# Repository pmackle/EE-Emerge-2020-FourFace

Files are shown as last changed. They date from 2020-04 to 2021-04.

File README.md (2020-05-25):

---
title: Readme
layout: template
filename: README
--- 

# EE-Emerge 2020: Four Face

FourFace is a capacitive touch, four player interactive game in the vein of the 80's electronic game, "Simon".  The basic premise of the game is a pattern of lights will emit for each player that they will then have to replicate. If they guess incorrectly, they are eliminated. With each round the patterns become more complex

## Table of Contents

1. [About the Project](#about-the-project)
1. [Getting Started](#getting-started)
    1. [Dependencies](#dependencies)
    1. [Installation](#installation)
1. [How to Get Help](#how-to-get-help)
1. [Authors](#authors)
1. [Acknowledgements](#acknowledgements)

# About the Project
FourFace is a project developed during the 2019/2020 academic year by undergraduates from EE-Emerge a group within the Department of Electrical and Computer Engineering at the University of California, Davis. FourFace is interactive memory game where four players compete against one another by replicating randomly generated patterns. As the rounds increase, the patterns become more difficult. Once a person fails to imitate the given pattern, they are eliminated. Last person to survive the remaining rounds is crowned the winner. At the core of FourFace's technology is CapSense technology and custom PCBs.

Features:
- CapSense Technology
- Custom PCB's
- 1-4 player game
- Adjustable Difficulty
- Portable
The mechanical design for the project is composed of a 15x15in cube with 9 acrylic tiles that face each player.

Our motivation for the project was to put a creative, more modern spin on a similar, but older game. We wanted to use our engineering skills to bring a faint idea into a reality by overseeing it through the whole product lifecycle. 

[Our Hackster.io website](https://www.hackster.io/fourface/fourface-1bf273)

**[Back to top](#table-of-contents)**

# Getting Started
These instructions will get you a copy of the project up and running on your local machine for development and testing purposes. See deployment for notes on how to deploy the project on a live system.

## Dependencies

### Required 
In order to build the firmware, [TI Code Composer](https://software-dl.ti.com/ccs/esd/documents/ccs_downloads.html) should be installed. When prompted select to add support for MSP430 and MSP432 microcontrollers. 

### Optional
Segger J-Link support can be added for MSP432, but is not required.

## Getting the Source

This project is [hosted on GitHub](hhttps://github.com/pmackle/EE-Emerge2020-FourFace). You can clone this project directly using this command:

```
git clone https://github.com/pmackle/EE-Emerge2020-FourFace
```

This will create a new root folder "EE-Emerge2020-FourFace" that will contain all projects for Four Face.

## Installation

1. Open Code Composer Studio
1. Create a new workspace 
    * File -> Switch Workspace -> Other
1. Browse to where the project repository was closed. 
1. Press launch
1. Import projects
    1. Project -> Import CCS Projects
    1. Press Browse
    1. Select root folder that was cloned.
    1. Press OK 
    1. Checkmark all projects
    1. Press Finish
1. Build each project one by one

**[Back to top](#table-of-contents)**

# How to Get Help

For help please contact one of the project [authors](#release-process).

**[Back to top](#table-of-contents)**

# Authors

* [Patrick Mackle](https://github.com/pmackle) - *Team Leader, Mechanical Design, Fabrication*
* [Anthony Pham](https://github.com/AnthonysPham) - *Mechanical Design, Fabrication*
* [Sophie Bolotin](https://github.com/sbolotin20) - *Website Design*
* [Noah Tarr](https://github.com/NoahTarr) - *Software Design*
* [Vanessa Liera](https://github.com/vpliera) - *Fabrication*
* [Victoria Liera](https://github.com/victorialiera) - *Fabrication*
* [Michelle Acoba](https://github.com/maacoba) - *Fabrication, Website Design*
* [Christian Gonzalez](https://github.com/christian-ee-emerge) - *Hardware & Mechanical Design, Fabrication*
* [Sean Alling](https://github.com/SeanAlling) - *Class TA*
* Andre Knoesen- *Professor*

**[Back to top](#table-of-contents)**

# Acknowledgments

UC Davis for giving us the opportunity to work together & Texas Instruments for sponsoring and allowing for FourFace to even become a reality.
A huge thank you to our professor Andre Knoessen and TA Sean Alling for their guidance in helping us stay on track with our goals and keep our sight on the big picture. 

**[Back to top](#table-of-contents)**

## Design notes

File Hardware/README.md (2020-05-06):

During the prototype phase, we used Texas Instruments MSP430 and MSP432 launchpads to test the capsense technology, the software of the
game, and any wirings we have in mind. Once we figured out what we wanted out of this project, we became designing our PCBs. We will 
continue to use the MSP432 launchpad as our master. The software we will be using to create our PCBs is CircuitMaker by Altium Circuit 
Maker.

Here is a little background information on why we decided to make custom PCBs. At first, we thought of having the nine LED strips 
connected to the face launchpad. Along with the nine capsense acylic panels, the numbers of connections needed became 18 wires plus a 
communication wire, bring the total to 19 wires. However, The MSP430 do not support this many connections. With this in mind, we created 
our PCBs. 

The main job of the face PCBs is to read whether the capsense is activated. If the PCB detects a change in capacitance, then the 
PCB will be able to communicate with the Master PCB through UART. 

START CHANGES
Add some images here of the hardware
END CHANGES

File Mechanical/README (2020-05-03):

  The software app we will be using to cad the design is AutoDesk Fusion 360. A laser cutter is needed to cut the wood sheets for the 
mechanical design. If you do no have a laser cutter, a box cutter will do. You will also need a 3D printer to print any needed parts.
  The overall design of the of the project is a cube, where each of the four adjacent sides make up the frames. Each frame will have a 
dimension of 15x15 inch. Within each frame, there are nine 4x4 inch acrylic panels with capacitive sensing technology, ultimately acting
as a "touch screen." Each frame has four layers, each having a specific mechanical function. The acrylic panel sits on top of the first
layer and the first layer is directly above thesecond layer. The first and second layer act in conjunction with each other by creating 
a stable configuration for the panel, which is the layer above, to sit evenly on the first layer. Because the acrylic panel has the same 
dimensions as the first layer, without the second layer being slightly larger, the panels would be unable to be securely stacked. The next
layer has a specific thickness of half an inch, which is the width the the LED strip we will be using. The LED strip will run along the 
square cutouts. The final layer allows wiring management. Once one frame is done, you have to do the same procedure three more times. To 
attach the layers of the frames, we recommend using wood glue. Now once all four frames are done, you can start assemblng the four 
faces together. In AutoDesk Fusion 360, we cadded a model called corner connector. This is a simple design to assemble the four frames
together. They will lay inside of the cube, in the corner. We can make holes to screw the corner connector and the frame together.
  Lets talk a little more about the acrylic panels with capsense technology. If you look at one acrylic square, you will see copper tape 
surrounding the perimeter. A wire is then soldered onto the copper tape so that we can connect the acrylic squares to the face 
PCB. This will act as a parallel plate while the person's hand will act as the other parallel plate. When the person makes contact with
the acrylic plate, the capacitance will change. If this change passes a certain threshold, the PCB will activate the LED strips.
  There are additional designs that makes the project look cleaner. One of the aesthetic choices is four wooden rectangular dowels. When
the four faces are assembled, the outside corners do not align with each other. By using the dowels, we cna make each face flush with 
each other. Another design choice is having a base and tower underneath the four faces. The tower will be a rectangular box that connects 
the four faces and the base. This will also give the game some height, allowing the players to stand when imitating the pattern. The base 
will be a simple box that houses the power supply.

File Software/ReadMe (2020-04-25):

This project will need four Texas Instruments' MSP430 and one MSP432 launchpad. To program these microcontrollers, we will 
be using Texas Instrument Code Composer Studio. In order to communicate between the master launchpad to the four face microcontroller,
we will be using Universal Asynchronous Receiver/Transmitter (UART) Communication. 
Overview of the Code:
The Master and faces will start up and initilize the game and players. The players will then have to ready up by touching the 
middle panel of the frame. Once readied up, the master will send a random pattern to each frame. The player will memorise the pattern
and imitate the pattern. If the pattern is incorrect, then the player will get eliminated. However, if the player manage to replicate it,
then the player goes onto the next round. There is two ways the game will end: three out of the four players gets eliminated or the 
predetermined set of rounds get completed before elimination occurs.

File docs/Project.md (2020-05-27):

---
title: Project
layout: template
filename: Project
--- 

# FourFace 
FourFace integrates capacitive touch sensing into a four-player interactive game in the vein of the 80's electronic game, "Simon". In the game, a pattern of lights emits and each player tries to replicate. If they guess incorrectly, the player is eliminated. The patterns become increasingly complex with new each round.   

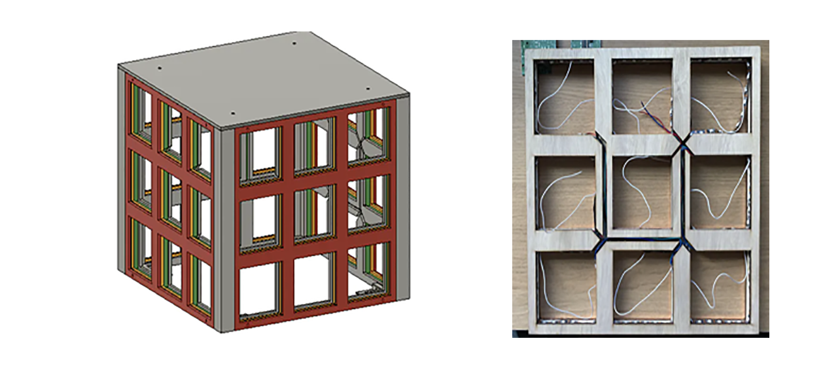
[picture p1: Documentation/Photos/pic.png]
test!


## Mechanical Design

All of the mechanical design was done through Autodesk Fusion 360. Fourface is a cube that consists of 4 sides called "Faces", with 9, 4x4in acrylic tiles. The laser cut sides are held together by 3D printed corner pieces. One whole face is 15x15in.

Each frame has four layers, each with their own specific mechanical function. The first layer and second layer stack such that acrylic tiles can be placed securely on each face. The next layer has bigger holes so as allow for the LED strip to sit flush with the top layers. The final layer allows for cleaner wiring in a specific order.

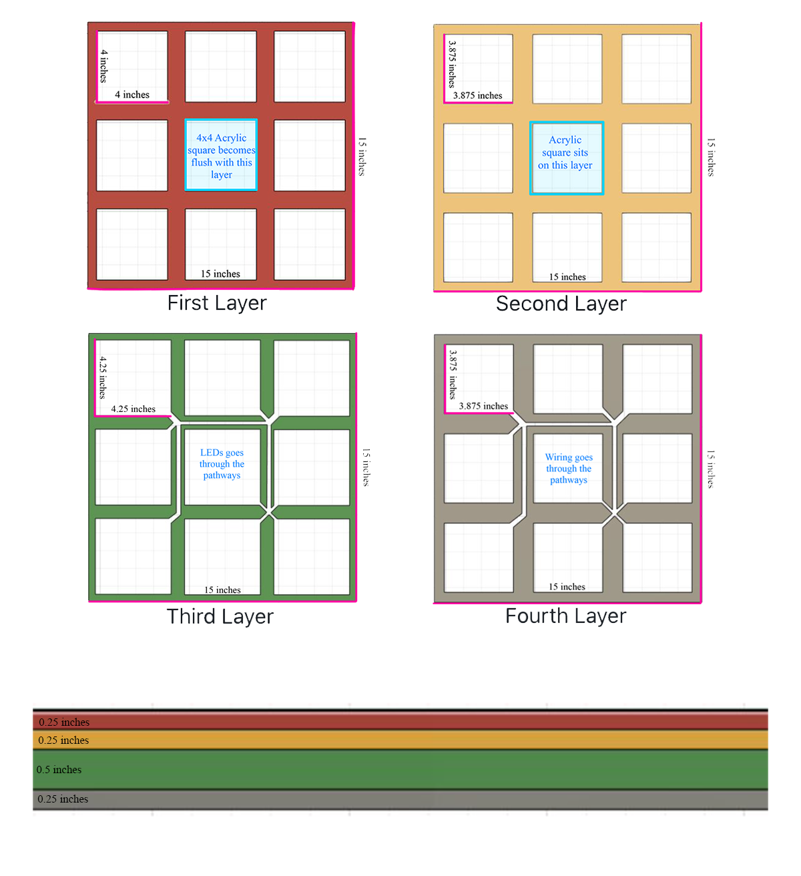
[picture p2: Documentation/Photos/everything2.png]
firstsecond!


## Software Design 

The project consists of four Texas Instruments' MSP430 and one MSP432 Launchpad. We use Universal Asynchronous Receiver/Transmitter (UART) Communication, allowing the communication between the master (MSP432) and slaves (MSP430). The master launchpad creates a random pattern and sends the pattern to the slaves. Once the pattern is received, the slaves display the pattern for the player to irepeat.

## Capacitive Touch

Texas Instruments' MSP430 has up to 16 capacitive touch pins embedded into its system. To build the capacitive touch system, we laser cut acrylic squares that acted as "touch screen buttons" for the users to press. Copper tape surrounds the tiles to allow for the system to recognize a change in capacitance. Wires are soldered onto the copper tape and connect to the PCB.

When a person makes contact (or comes near) the acrylic or copper tape, the capacitance changes. In summary, the finger and the system act as parallel plate capacitors. Our code counts the number of charges and discharges to 5 volts. When the capacitive touch system is untouched, there is a certain "untouched" threshold value. Because capacitance is inversely proportional to distance, we are able to use that change and tell the microcontroller that the tile has been touched. The microcontroller then compares the tile touched with the pattern that was emitted, to make sure the correct tile was touched.

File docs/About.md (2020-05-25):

---
title: About
layout: template
filename: About
--- 

FourFace is a project developed during the 2019/2020 academic year by undergraduates from EE-Emerge a group within the Department of Electrical and Computer Engineering at the University of California, Davis. FourFace is interactive memory game where four players compete against one another by replicating randomly generated patterns. As the rounds increase, the patterns become more difficult. Once a person fails to imitate the given pattern, they are eliminated. Last person to survive the remaining rounds is crowned the winner. At the core of FourFace's technology is CapSense technology and custom PCBs.

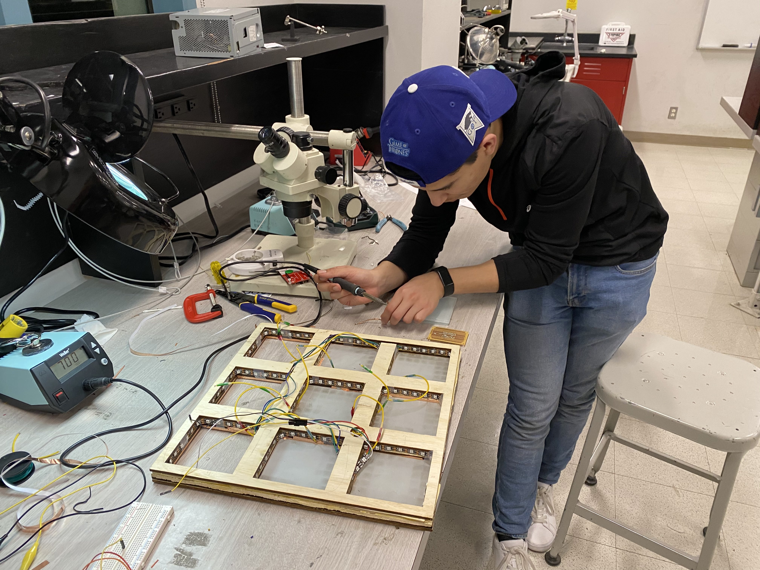
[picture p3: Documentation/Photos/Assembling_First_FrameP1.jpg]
Frame!


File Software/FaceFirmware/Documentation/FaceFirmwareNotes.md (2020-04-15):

# Four Face Firmware Notes

## Slave 

- Implemented with a MSP430
    * Slave communicates to the master using UART. 
        - UART is used since to meet timing requirements for the neopixels, the SPI peripheral is used. On this MSP430 the hardware I2C and the SPI share the same pins.
        - Master sends two bytes of data to the slave
            * Byte 0: 0-8 which corresponds to the square led square. 
            * Byte 1: 0-3 which corresponds to the color that the square should be.
        - Slave sends the master nine bytes
            * Each byte represent one square and the current color of the square.

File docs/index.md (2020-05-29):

---
title: FourFace
layout: template
filename: index
--- 

<p align="center">
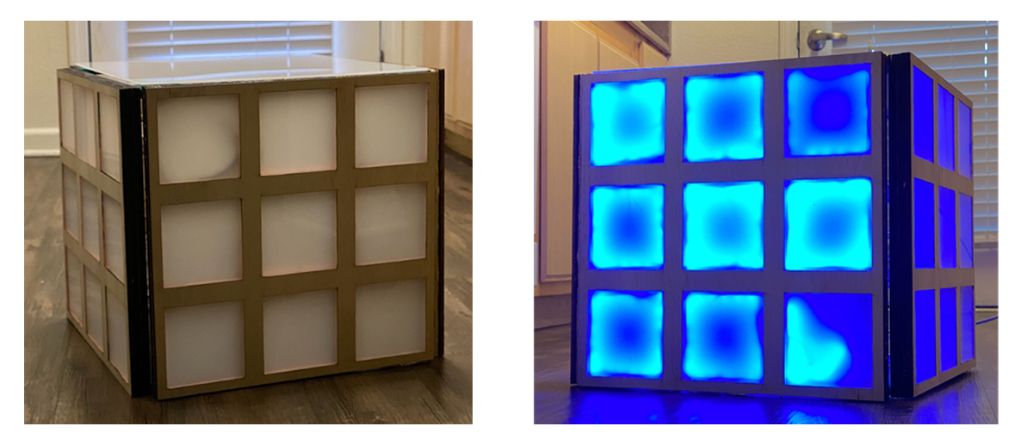
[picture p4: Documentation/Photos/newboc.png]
THE CUBE!!!!!
  
</p>

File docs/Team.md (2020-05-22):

---
title: Team
layout: template
filename: Team
--- 

# Meet Our Team

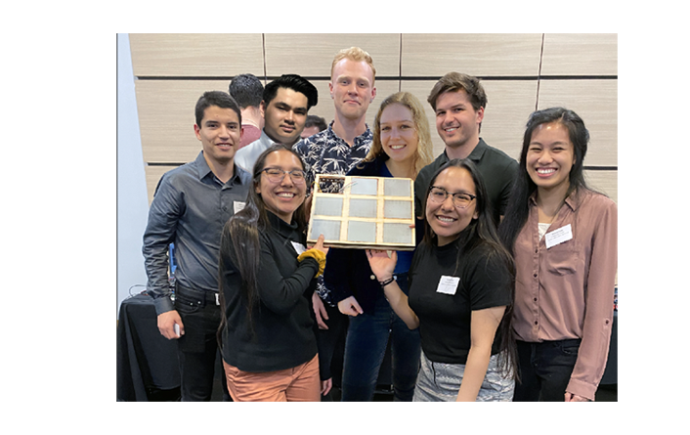
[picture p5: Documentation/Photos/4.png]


<div markdown="1">
<p align="center">
  EE-Emerge is part of the Department of Electrical and Computer Engineering at the University of California, Davis. Within a year, sophomores and juniors conceive, design, and build an interactive electronic system. Texas Instruments sponsors EE-Emerge.
</p>
</div>

| | | |
|:---:|:---:|:---:|
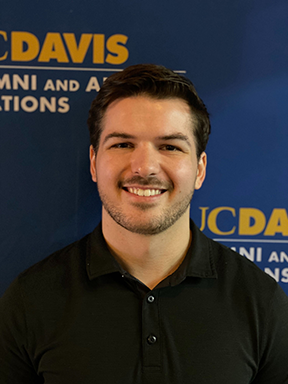
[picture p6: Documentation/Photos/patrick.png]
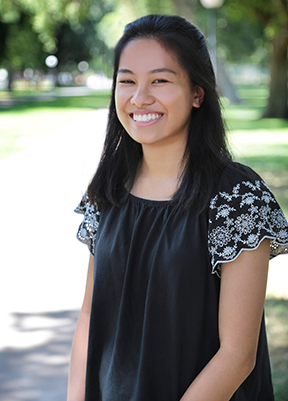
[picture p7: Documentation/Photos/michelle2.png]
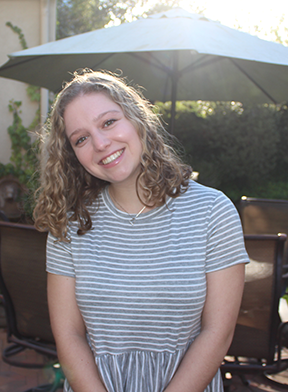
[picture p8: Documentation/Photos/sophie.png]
| |  | |
| **Patrick Mackle** <br/> **Team Leader** <br/> Electrical & Computer Engineering Major.<br/> Third Year <br/> I enjoy long walks on the beach. |**Michelle Acoba** <br/> Electrical Engineering Major <br/> Third Year <br/> I play piano! |**Sophie Bolotin** <br/> Computer Science & Engineering Major <br/> Third Year <br/> I love to bake! |
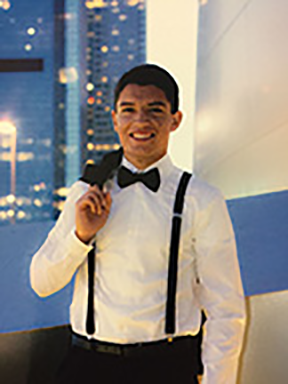
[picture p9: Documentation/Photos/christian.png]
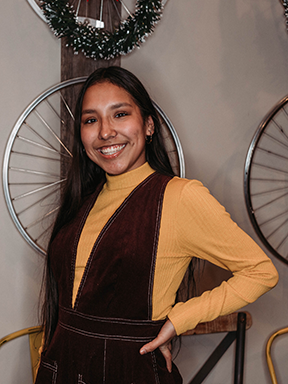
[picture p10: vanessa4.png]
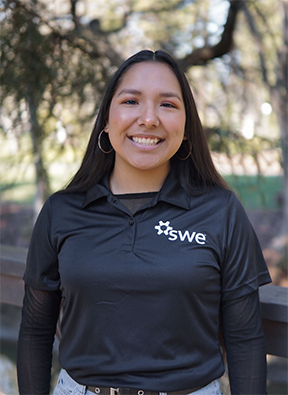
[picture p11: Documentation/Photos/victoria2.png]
||  ||
|**Christian Gonzalez** <br/> Electrical Engineering Major <br/> Third Year <br/> I enjoy playing soccer.|**Vanessa Liera** <br/> Electrical Engineering Major <br/> Second Year <br/>I like to dance. |**Victoria Liera** <br/> Electrical Engineering Major <br/>Second Year<br/> I have a twin.|
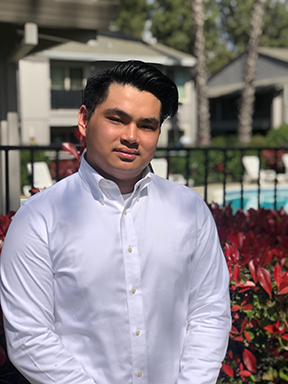
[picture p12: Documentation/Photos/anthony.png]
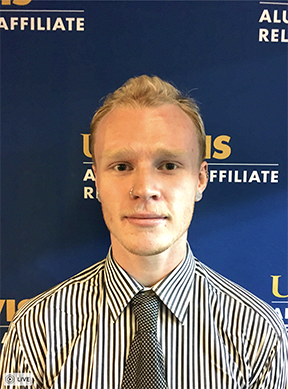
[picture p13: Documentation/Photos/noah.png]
| |  ||
|**Anthony Pham** <br/> Electrical Engineering Major<br/> Second Year <br/> My eyes are a negative 8. |**Noah Tarr** <br/> Computer Engineering Major <br/> Third Year <br/> I love running and snowboarding||

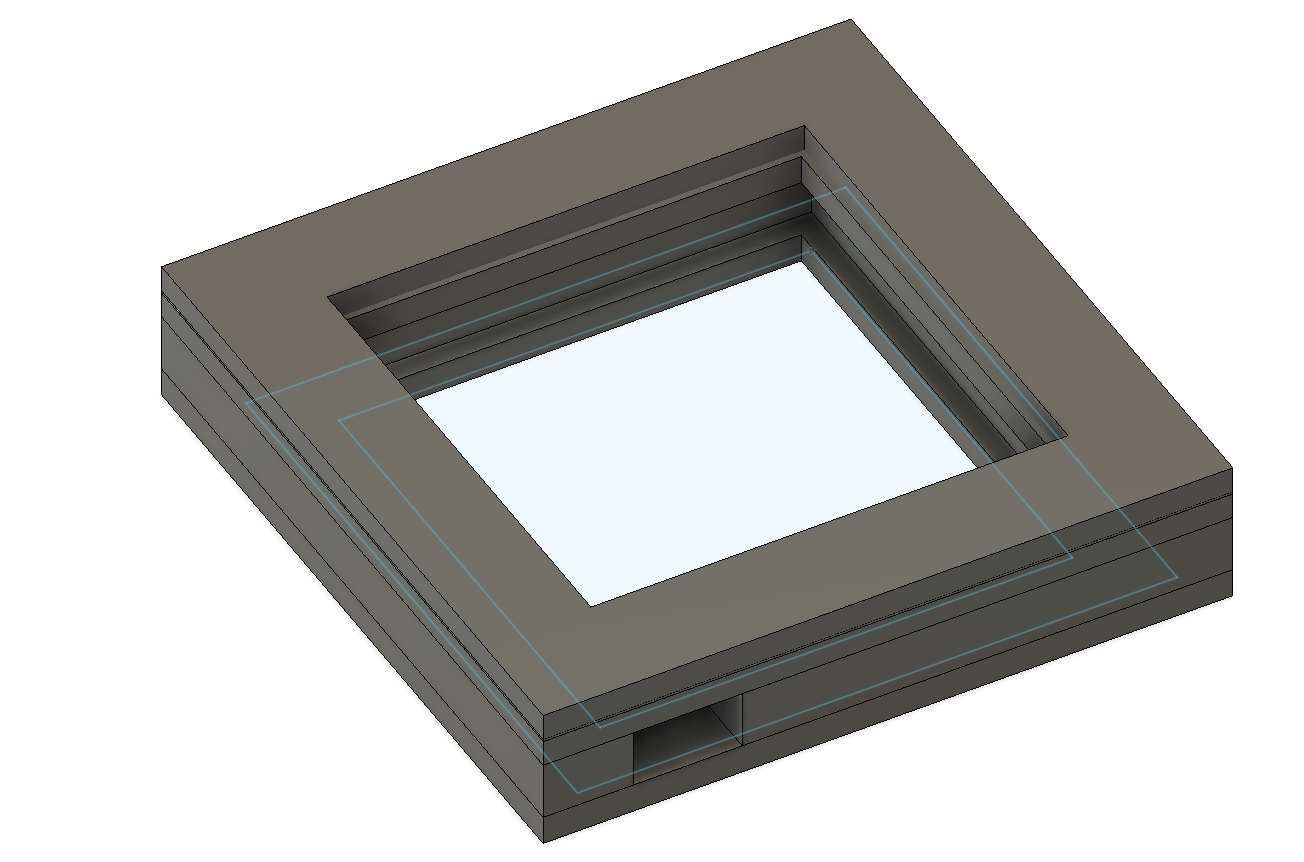
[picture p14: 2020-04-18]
Mechanical/OneSquarePrototype/OneSqPrototype.PNG

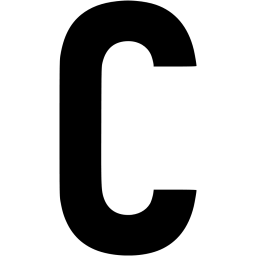
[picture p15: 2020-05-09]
docs/Images/C.png

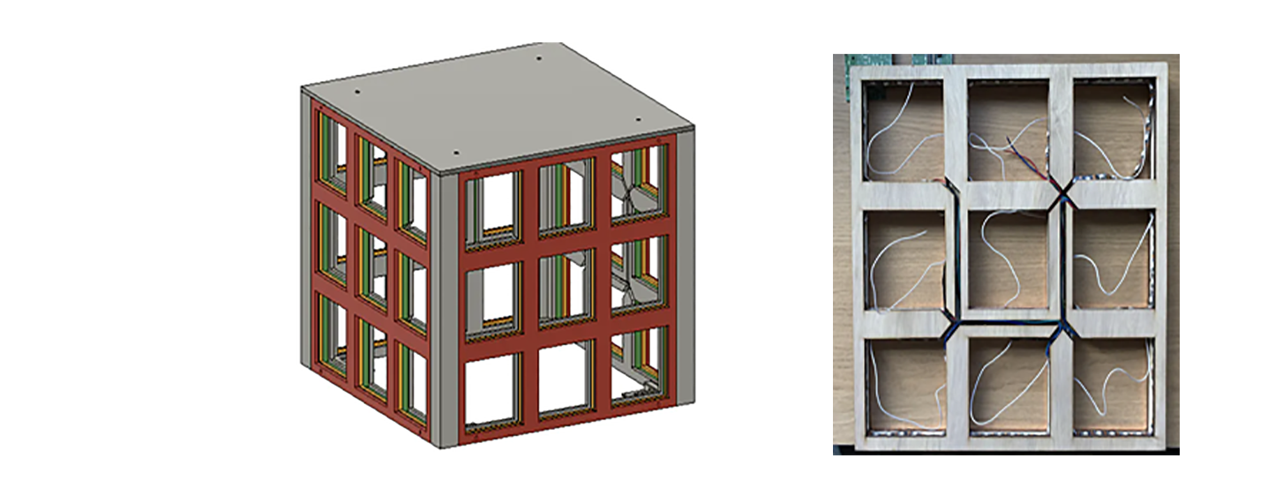
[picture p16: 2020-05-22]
Documentation/Photos/pics.png

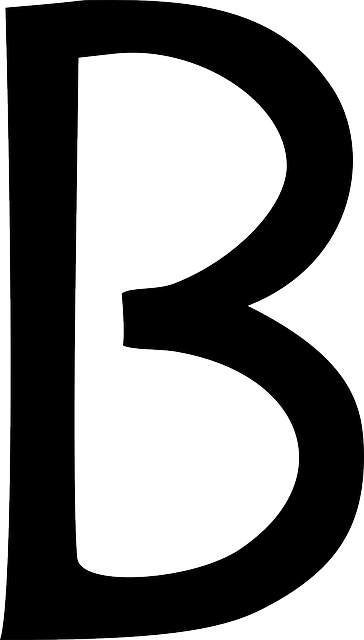
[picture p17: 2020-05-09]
docs/Images/B.png

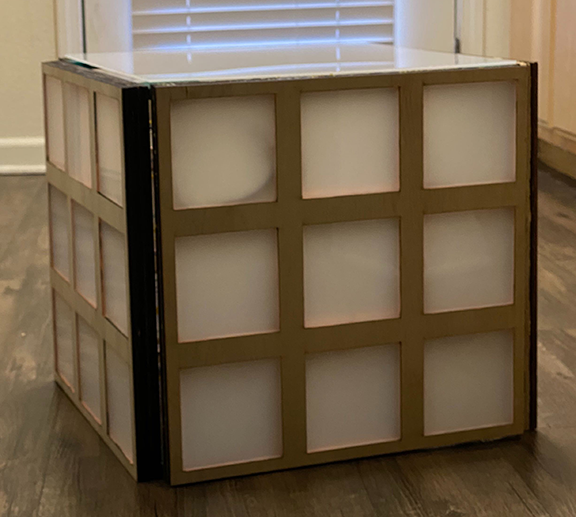
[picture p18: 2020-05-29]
Documentation/Photos/boc.png

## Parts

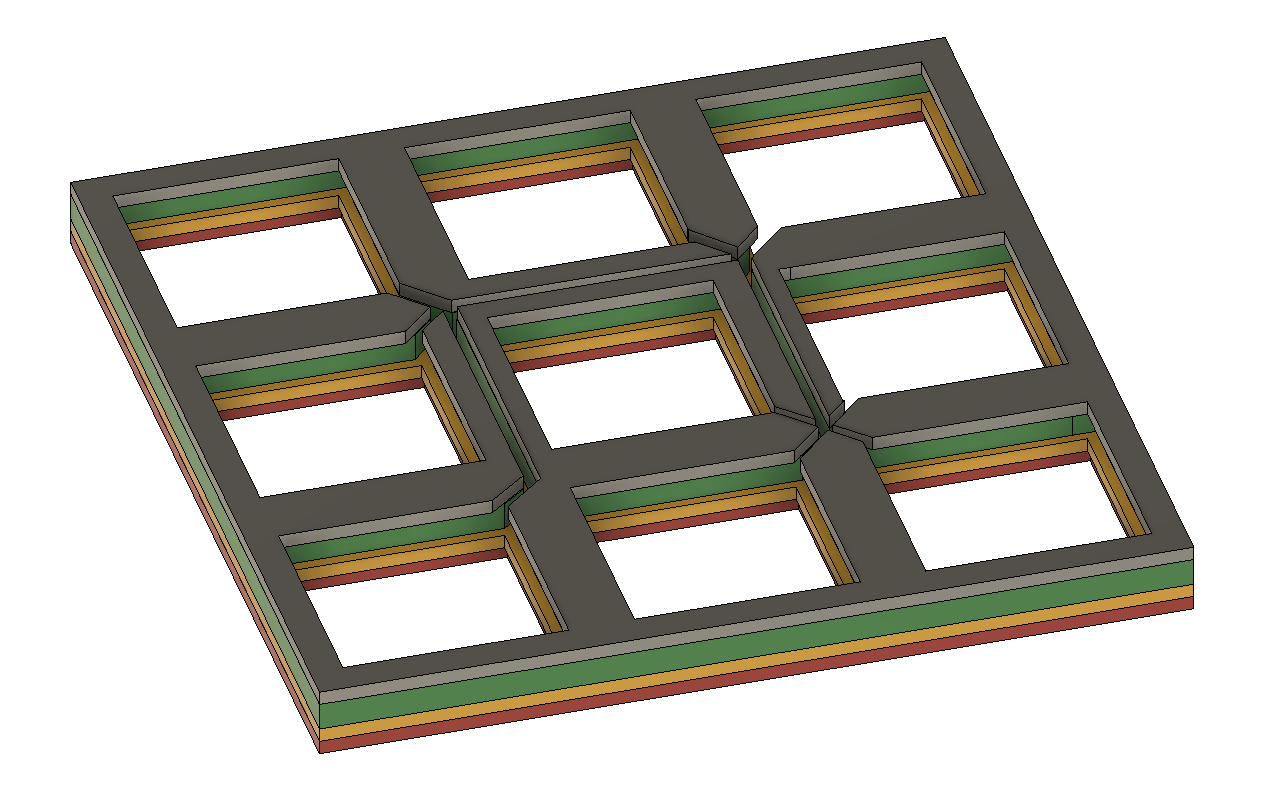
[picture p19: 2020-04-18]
Mechanical/Components/FourFaceLayers Back.PNG

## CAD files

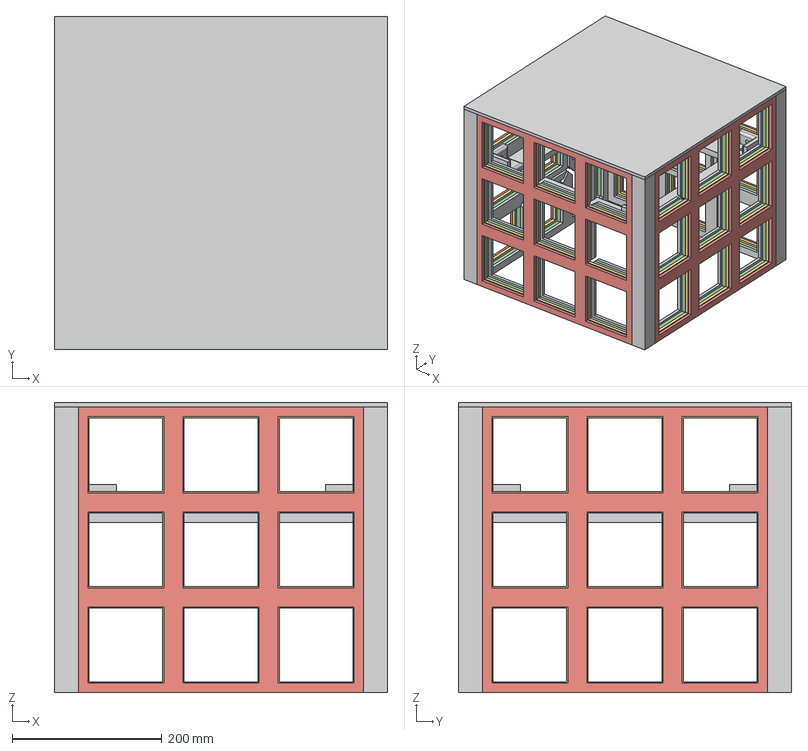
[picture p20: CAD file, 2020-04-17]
Mechanical/Components/Assembly v6.step
444.5 x 444.5 x 387.4 mm
OneFace x 4
Frame 3
Corner Cube Fastener
Dowel
Top Cover
Corner Cube Fastener v5(Mirror)
Dowel v2(Mirror)
Corner Cube Fastener v5(Mirror) (1)
Dowel v2(Mirror) (1)
Corner Cube Fastener v5(Mirror)(Mirror)
Dowel v2(Mirror)(Mirror)

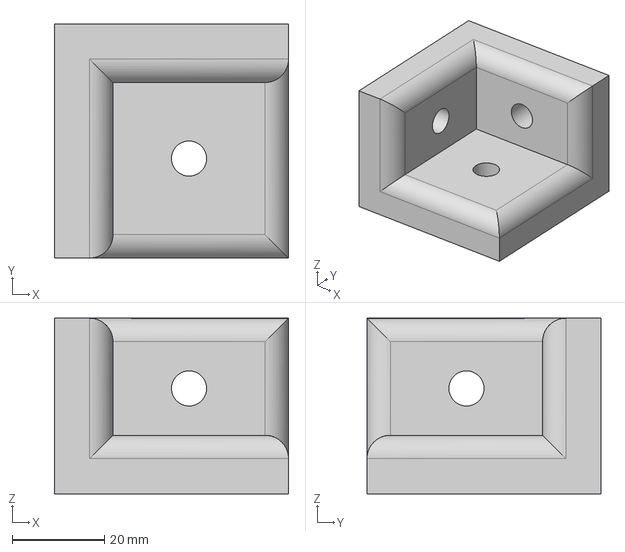
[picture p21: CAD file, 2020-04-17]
Mechanical/Components/Corner Cube Fastener v5.step
50.8 x 50.8 x 38.1 mm

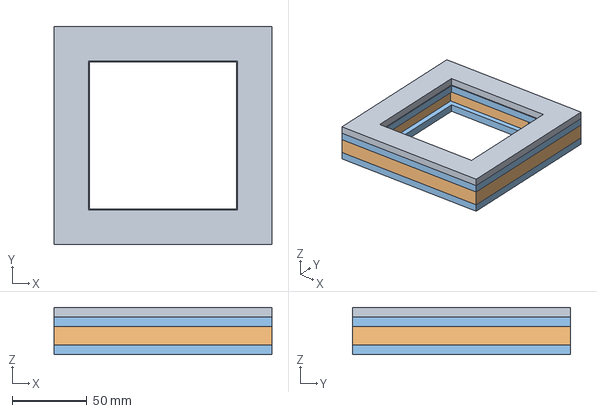
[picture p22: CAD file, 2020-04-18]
Mechanical/OneSquarePrototype/OneSquarePrototype v6.step
146.1 x 146.0 x 31.8 mm

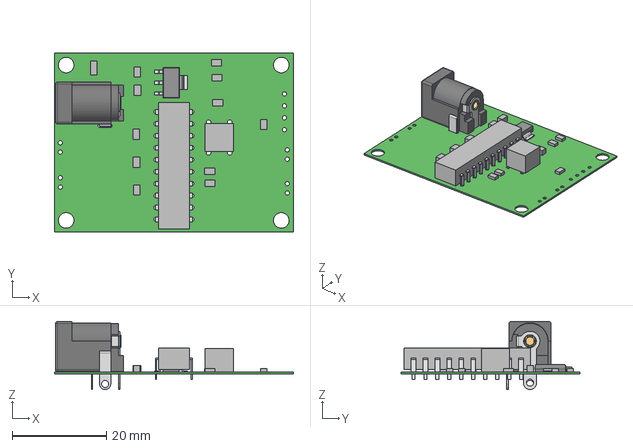
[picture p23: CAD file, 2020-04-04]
Mechanical/PCB/Central PCB.step
50.8 x 38.1 x 14.5 mm

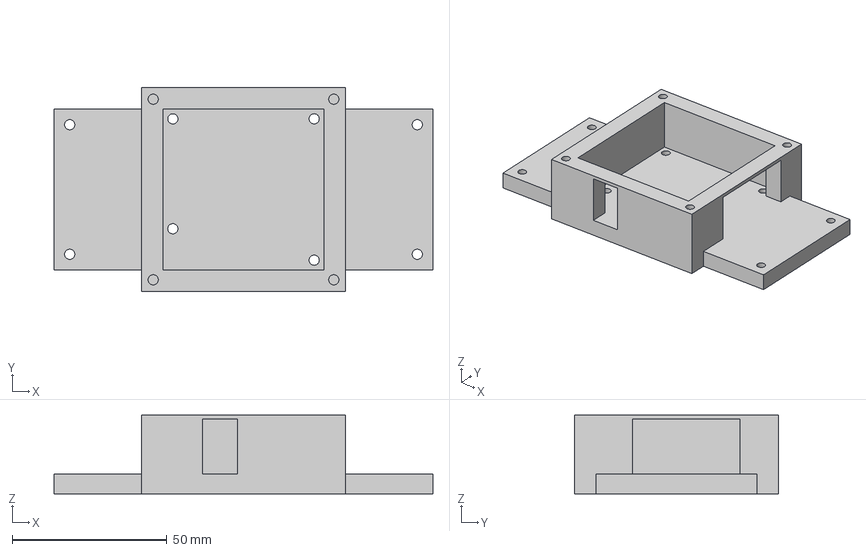
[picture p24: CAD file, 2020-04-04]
Mechanical/PCB/Face PCB Enclosure.step
122.6 x 66.0 x 25.4 mm

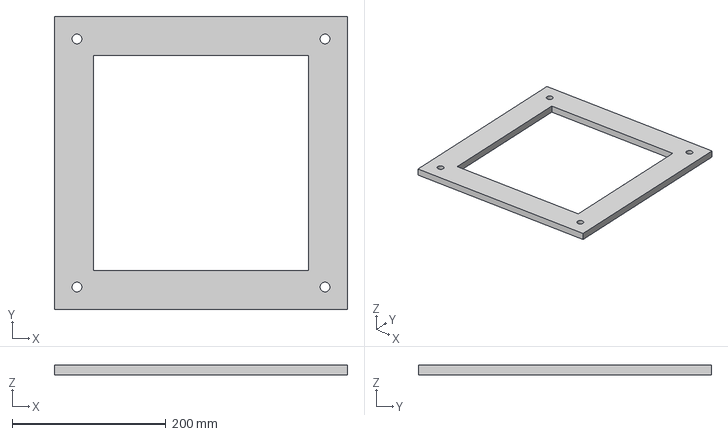
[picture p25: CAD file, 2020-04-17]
Mechanical/Components/Frame 3 v7.step
381.0 x 381.0 x 12.7 mm

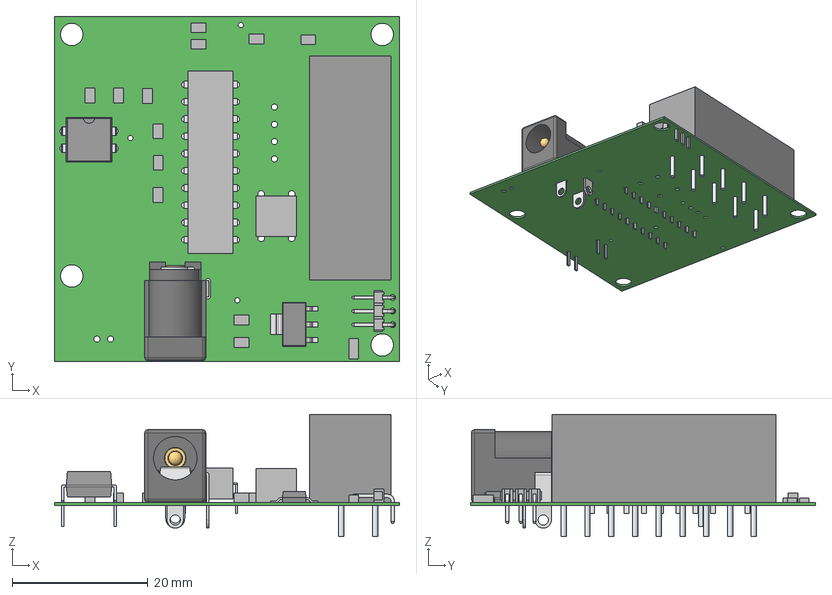
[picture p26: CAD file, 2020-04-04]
Mechanical/PCB/Face PCB.step
50.8 x 50.8 x 18.0 mm

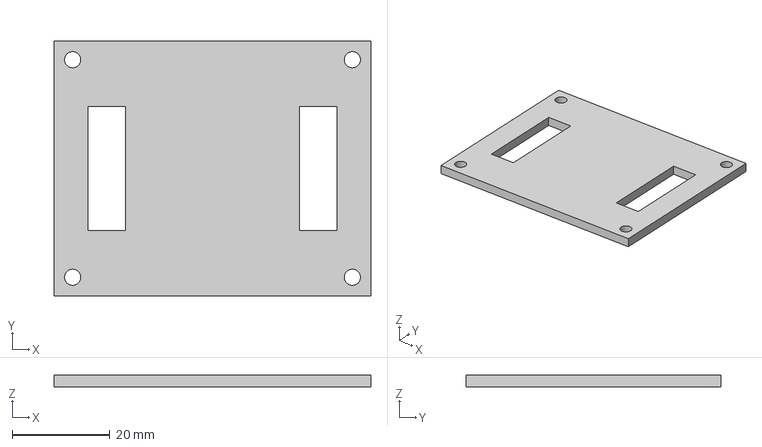
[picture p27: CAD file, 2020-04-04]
Mechanical/PCB/Central PCB Enclosure Lid.step
64.8 x 52.1 x 2.54 mm

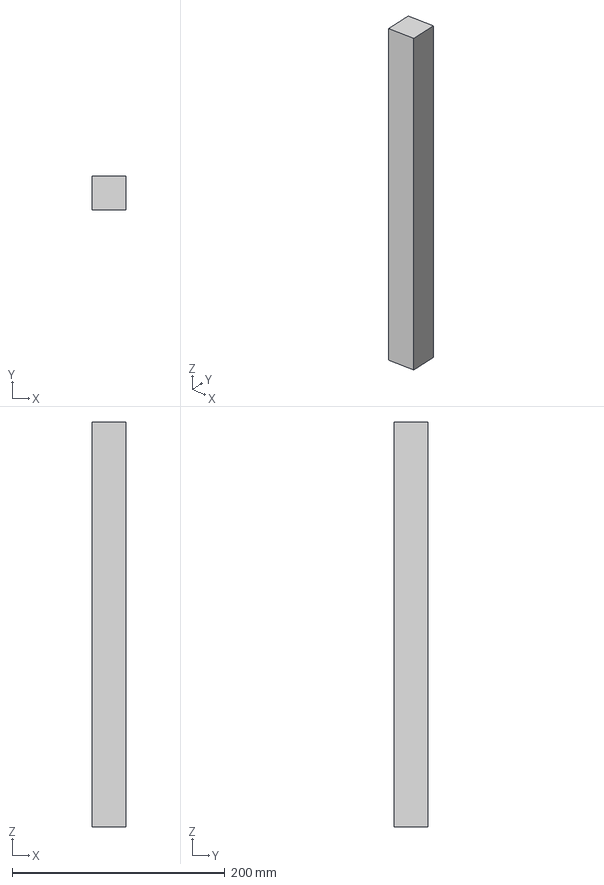
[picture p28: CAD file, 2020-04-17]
Mechanical/Components/Dowel v2.step
31.8 x 31.8 x 381.0 mm

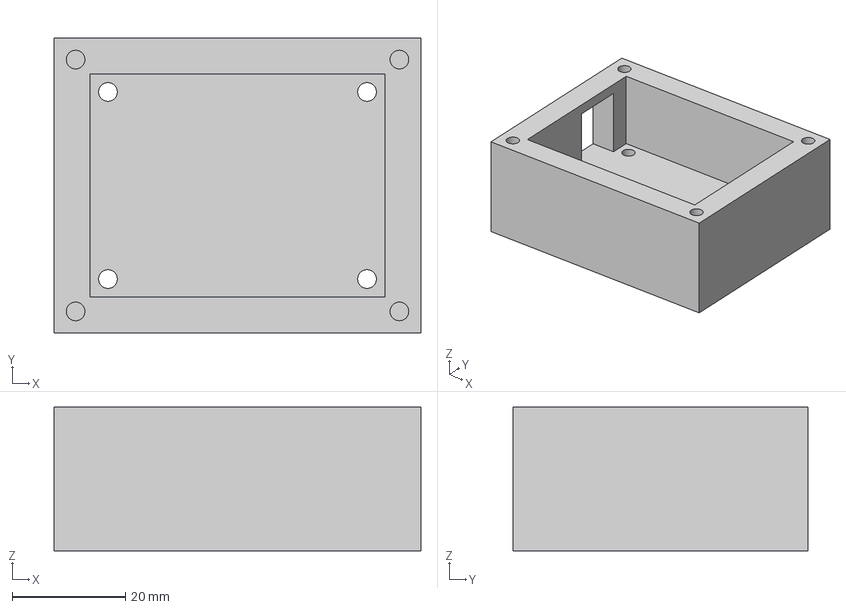
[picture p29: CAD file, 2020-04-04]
Mechanical/PCB/Central PCB Enclosure.step
64.8 x 52.1 x 25.4 mm

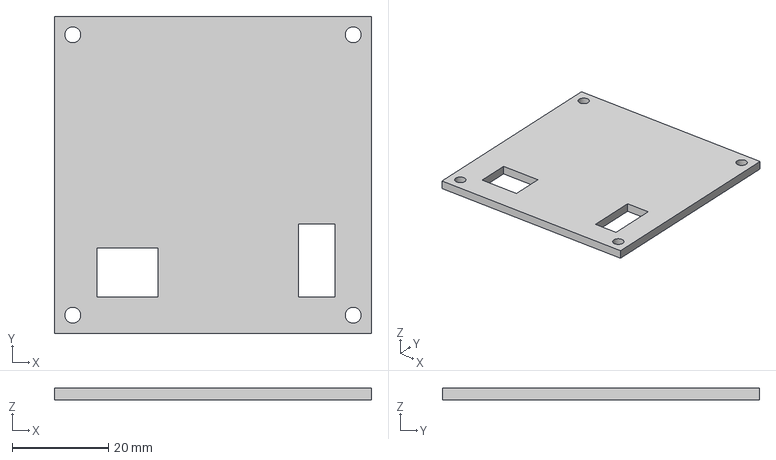
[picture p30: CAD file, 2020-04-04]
Mechanical/PCB/Face PCB Enclosure Lid.step
66.0 x 66.0 x 2.54 mm

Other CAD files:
Software/FaceFirmware/Debug__TI/Source/main.obj
Software/FaceFirmware/Debug__TI/Source/ws2812.obj
Software/FaceFirmware/Debug__TI/Source/CTS_Layer.obj
Software/FaceFirmware/Debug__TI/Source/CTS_HAL.obj
Software/FaceFirmware/Debug__TI/Source/structure.obj
Mechanical/Components/One Face.f3d
Mechanical/Components/Tower+Base.f3d

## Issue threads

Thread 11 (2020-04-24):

Hardware Folder

SeanAlling, 2020-04-24:
Hardware folder should be organized as the following
* Center PCB
    * Altium Project
    * Documentation
        * Bill of materials
        * Gerbers
        * PDF schematic
        * PDF 3d model PCB
        * PDF top and bottom gerbers
* Face PCB
    * Altium Project
    * Documentation
        * Bill of materials
        * Gerbers
        * PDF schematic
        * PDF 3d model PCB
        * PDF top and bottom gerbers

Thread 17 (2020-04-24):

Missing wiring diagram

SeanAlling, 2020-04-24:
The mechanical folder should contain a wiring diagram.. The wiring diagram should show how each of the components for the entire system are wired together.

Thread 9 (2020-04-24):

Documentation Folder Issues

SeanAlling, 2020-04-24:
Within the documentation folder there are multiple docx files. It is preferred to use either plain text or Markdwn on GitHib as those can be rendered whereas docx files are required to be downloaded first.

Switch the docx files to text or markdown.

Also seems to be team meeting minutes with in the folder. These should not be put here as they are not related to the actual project.

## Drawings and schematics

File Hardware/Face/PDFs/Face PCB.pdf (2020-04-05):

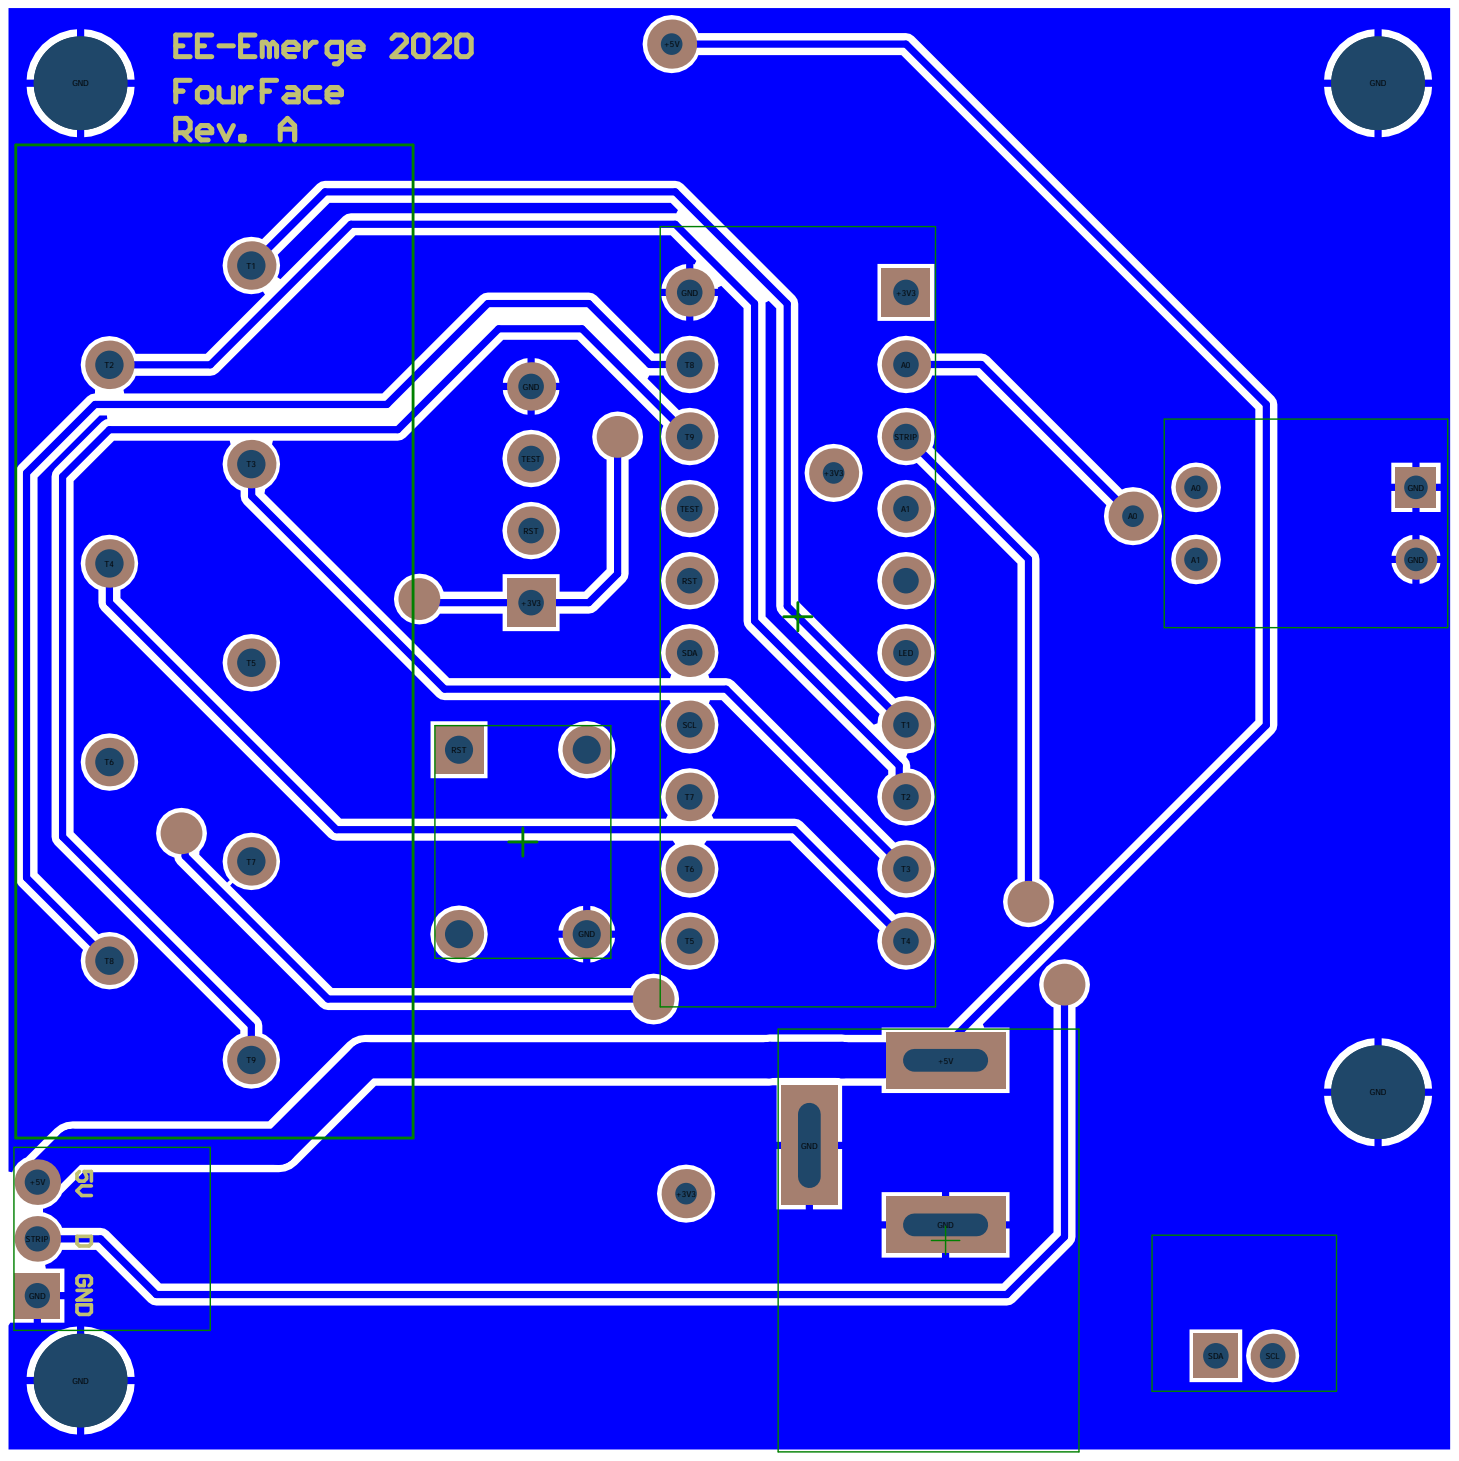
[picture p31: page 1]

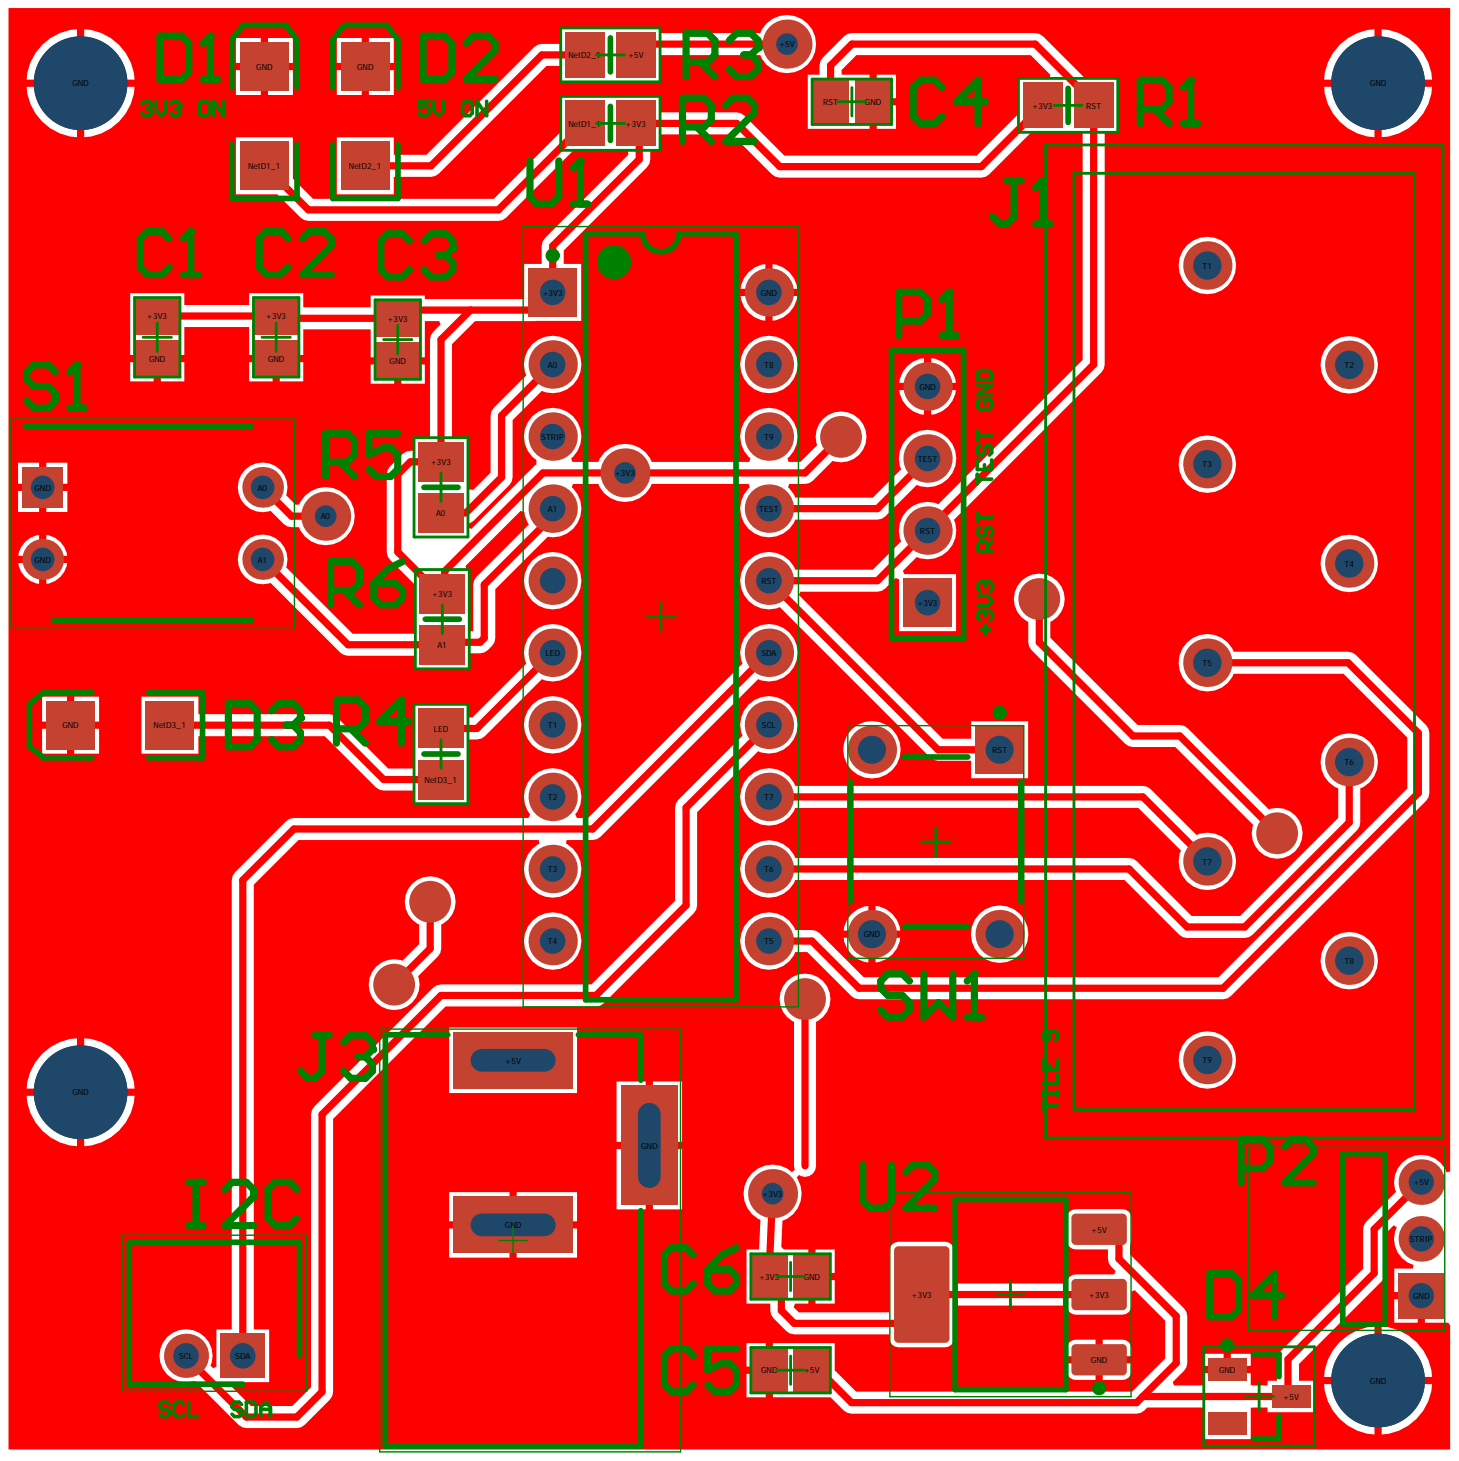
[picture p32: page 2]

GND GND T8 T8 T9 T9

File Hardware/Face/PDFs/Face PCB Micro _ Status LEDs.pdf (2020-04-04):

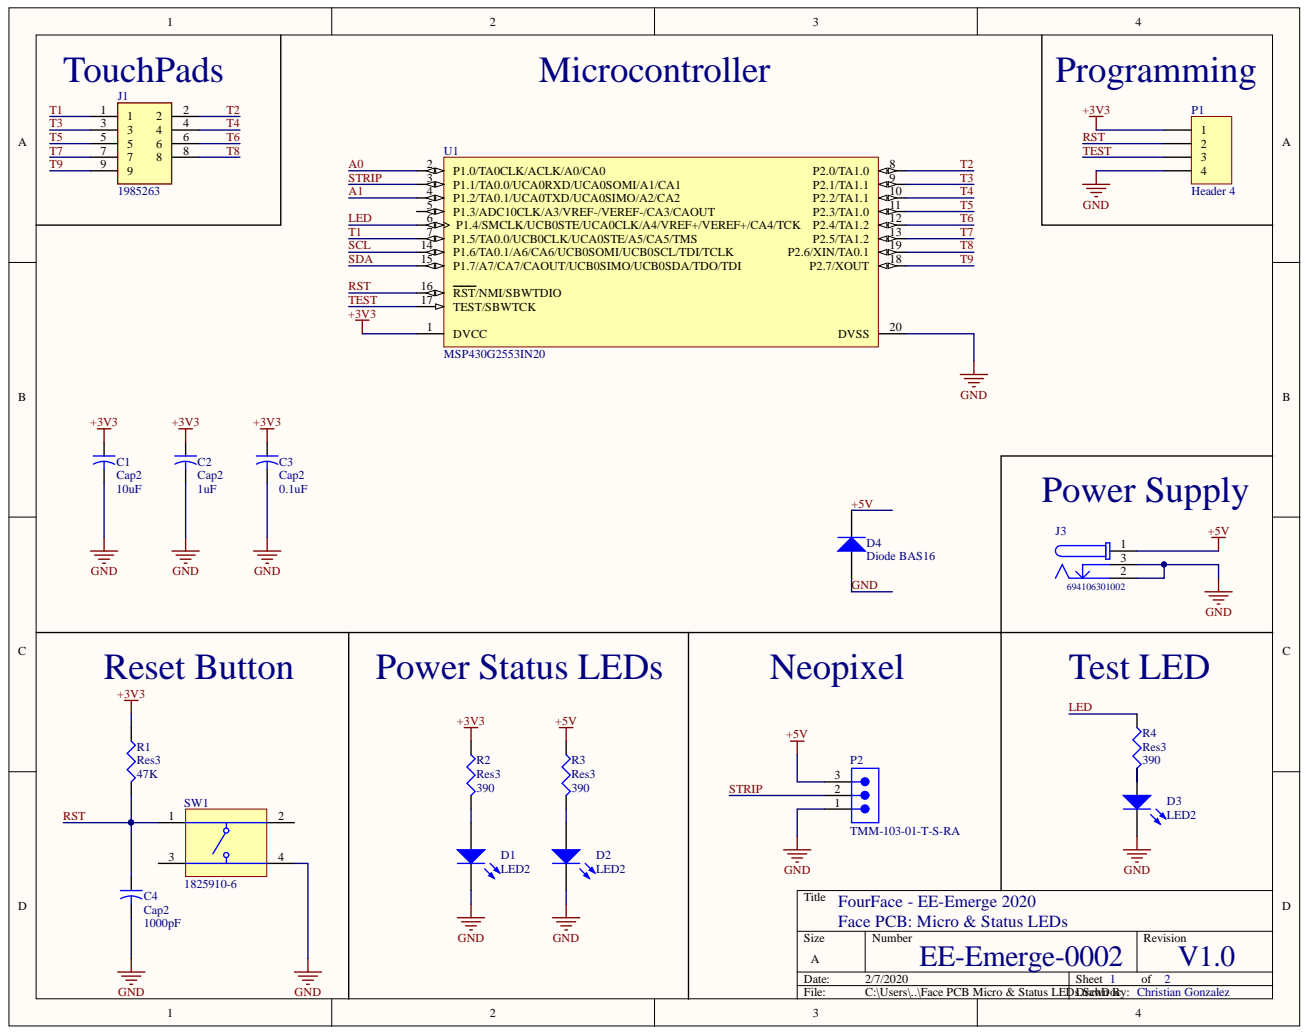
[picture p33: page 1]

Power Status LEDs GND

sD.SracwhDn ocBy: Chri

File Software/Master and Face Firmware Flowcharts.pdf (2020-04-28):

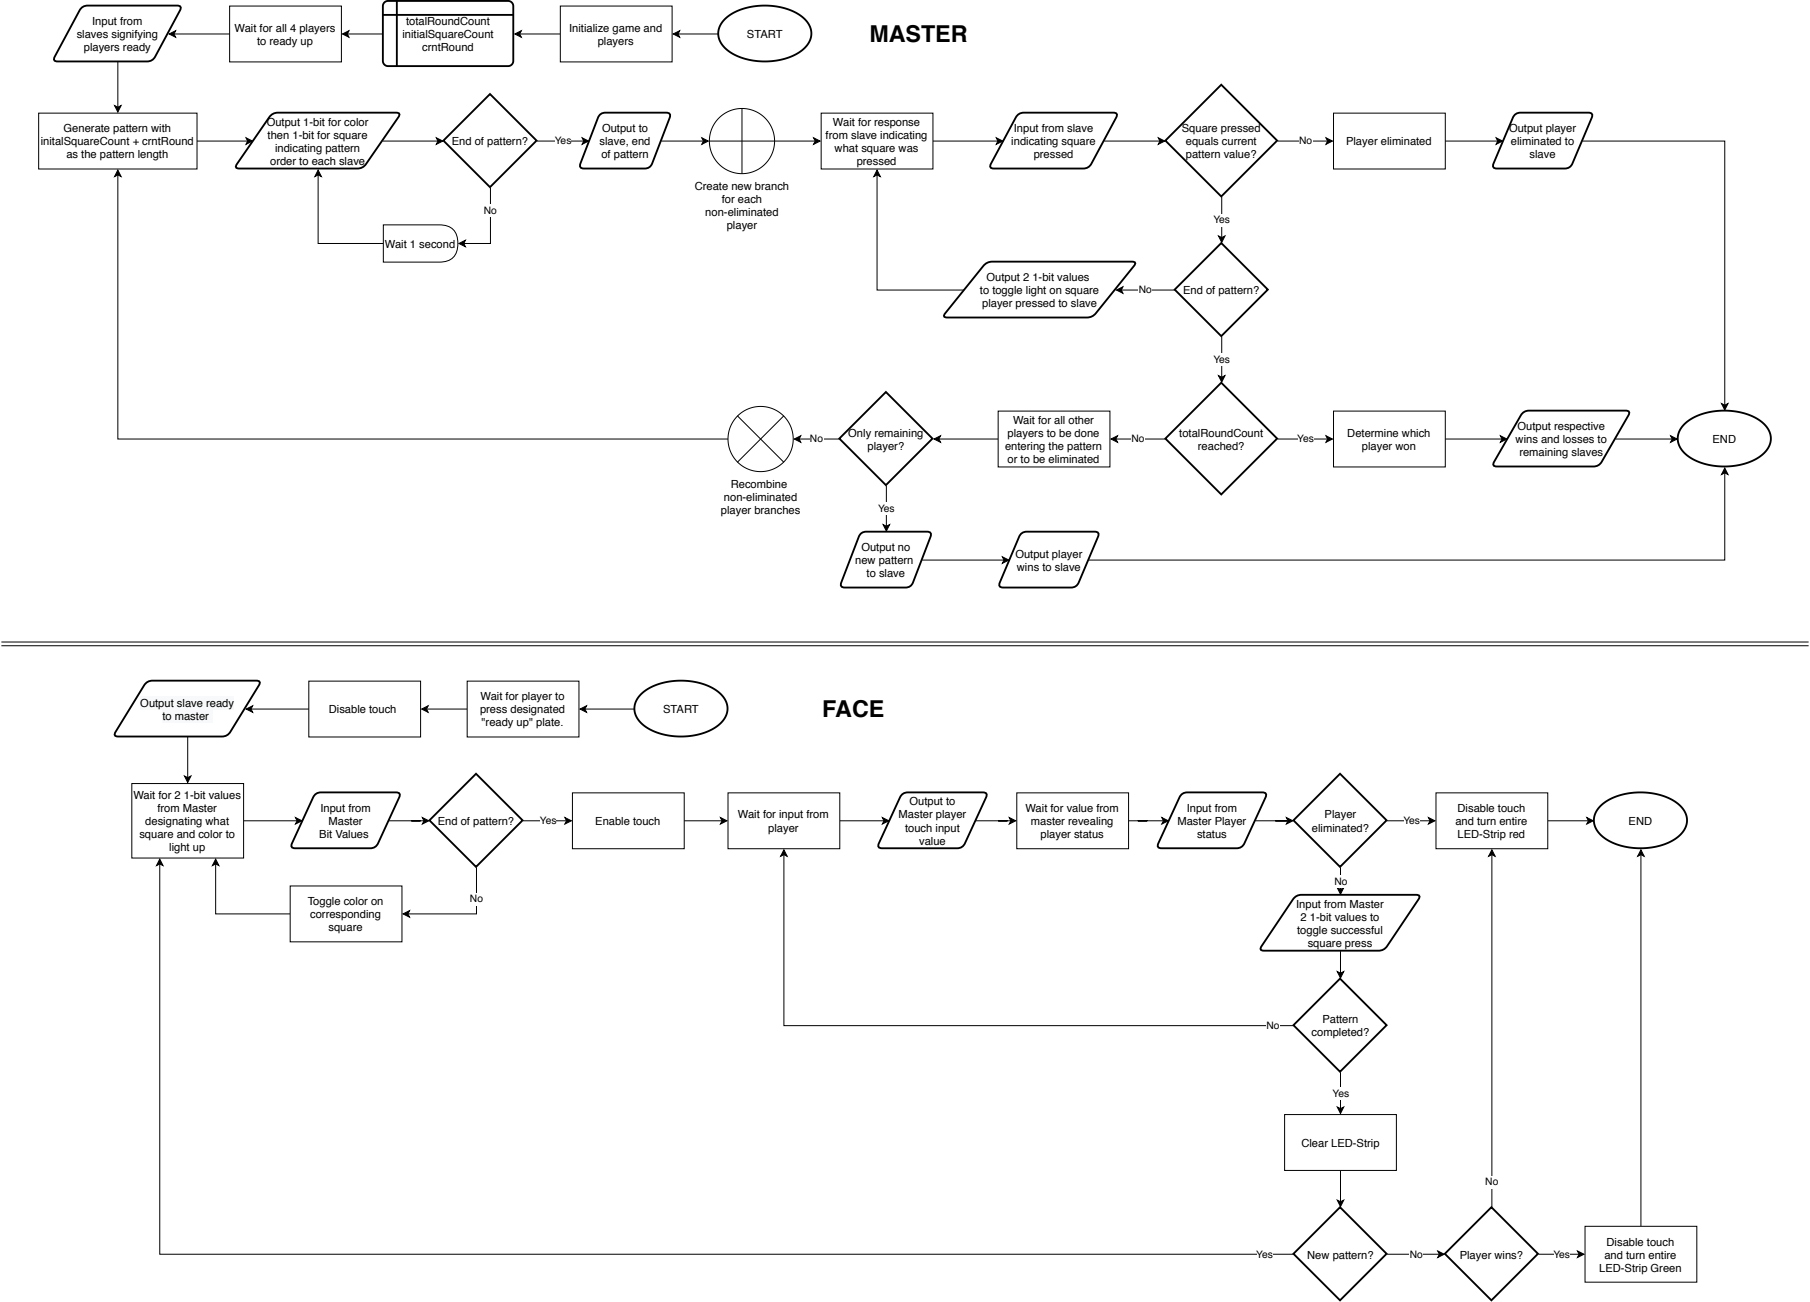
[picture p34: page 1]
to master; START; Input from Master Bit Values; Yes; End of pattern?; Enable touch; Wait for input from; player; Output to Master player touch input value; Input from Master Player status; Player eliminated?; END; Pattern completed?; New pattern?; Player wins?; FACE; MASTER Initialize game and; players; totalRoundCount initialSquareCount crntRound; Input from slaves signifying players ready; Square pressed equals current pattern value?; totalRoundCount reached?; Player eliminated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

Wait for all 4 players
to ready up

Output 1-bit for color
then 1-bit for square
indicating pattern
order to each slave

Wait for response
from slave indicating
what square was
pressed

Generate pattern with
initalSquareCount + crntRound
as the pattern length

Input from slave
indicating square

End of pattern?

Create new branch
for each
non-eliminated
player

Output 2 1-bit values
to toggle light on square
player pressed to slave

Wait for all other
players to be done
entering the pattern
or to be eliminated

Output respective
wins and losses to
remaining slaves

Output player
wins to slave

Disable touch Output slave ready

Wait for player to
press designated
"ready up" plate.

Wait for 2 1-bit values
from Master
designating what
square and color to
light up

Wait for value from
master revealing
player status

Disable touch
and turn entire
LED-Strip red

Toggle color on
corresponding
square

Input from Master
2 1-bit values to
toggle successful
square press

Clear LED-Strip

LED-Strip Green

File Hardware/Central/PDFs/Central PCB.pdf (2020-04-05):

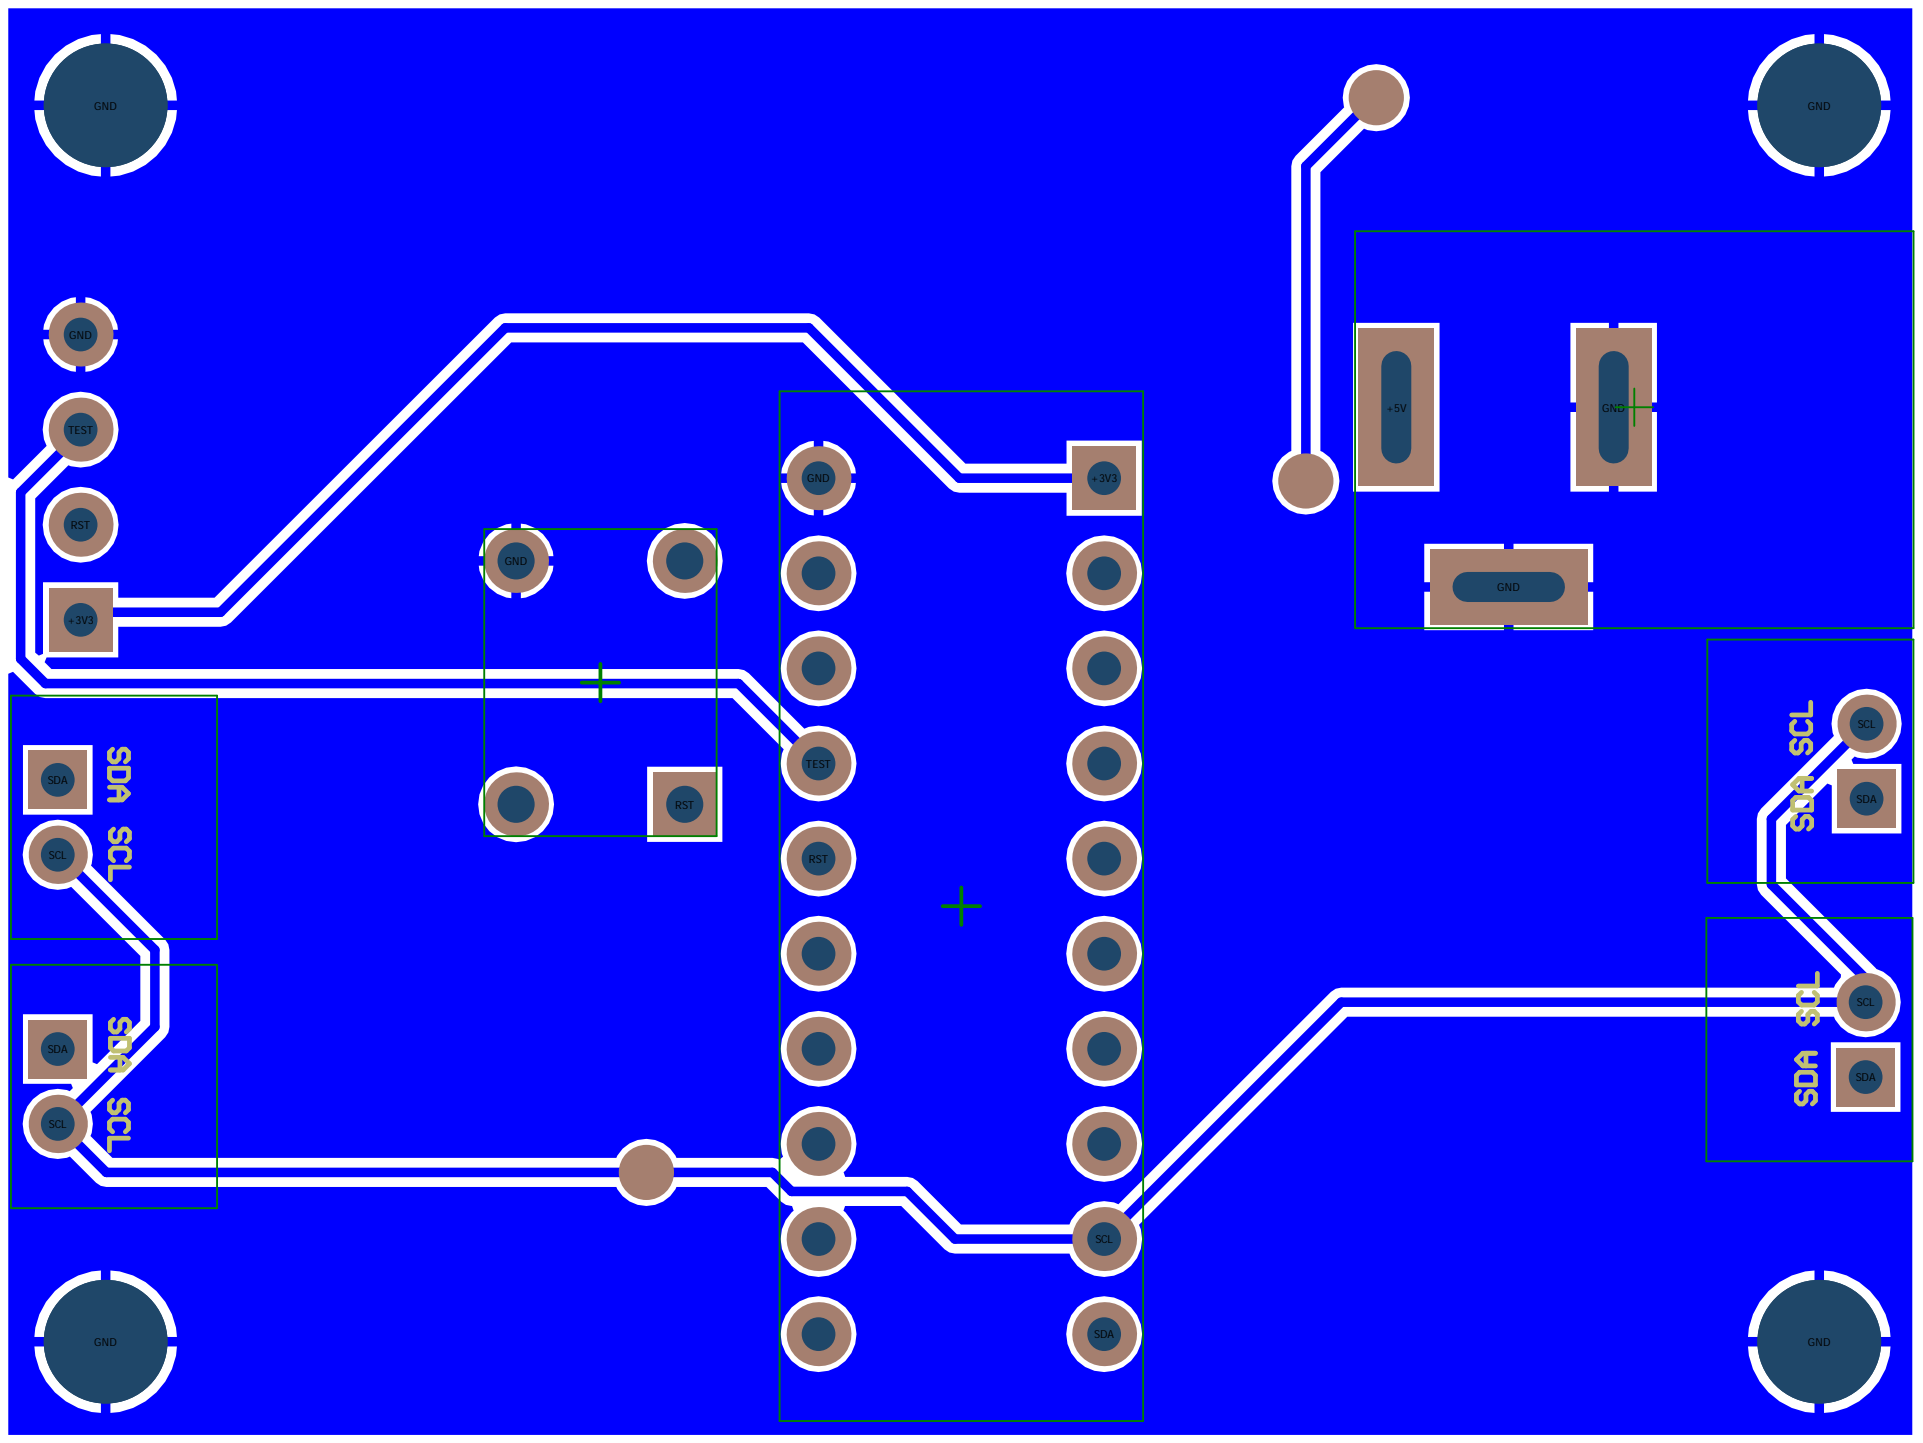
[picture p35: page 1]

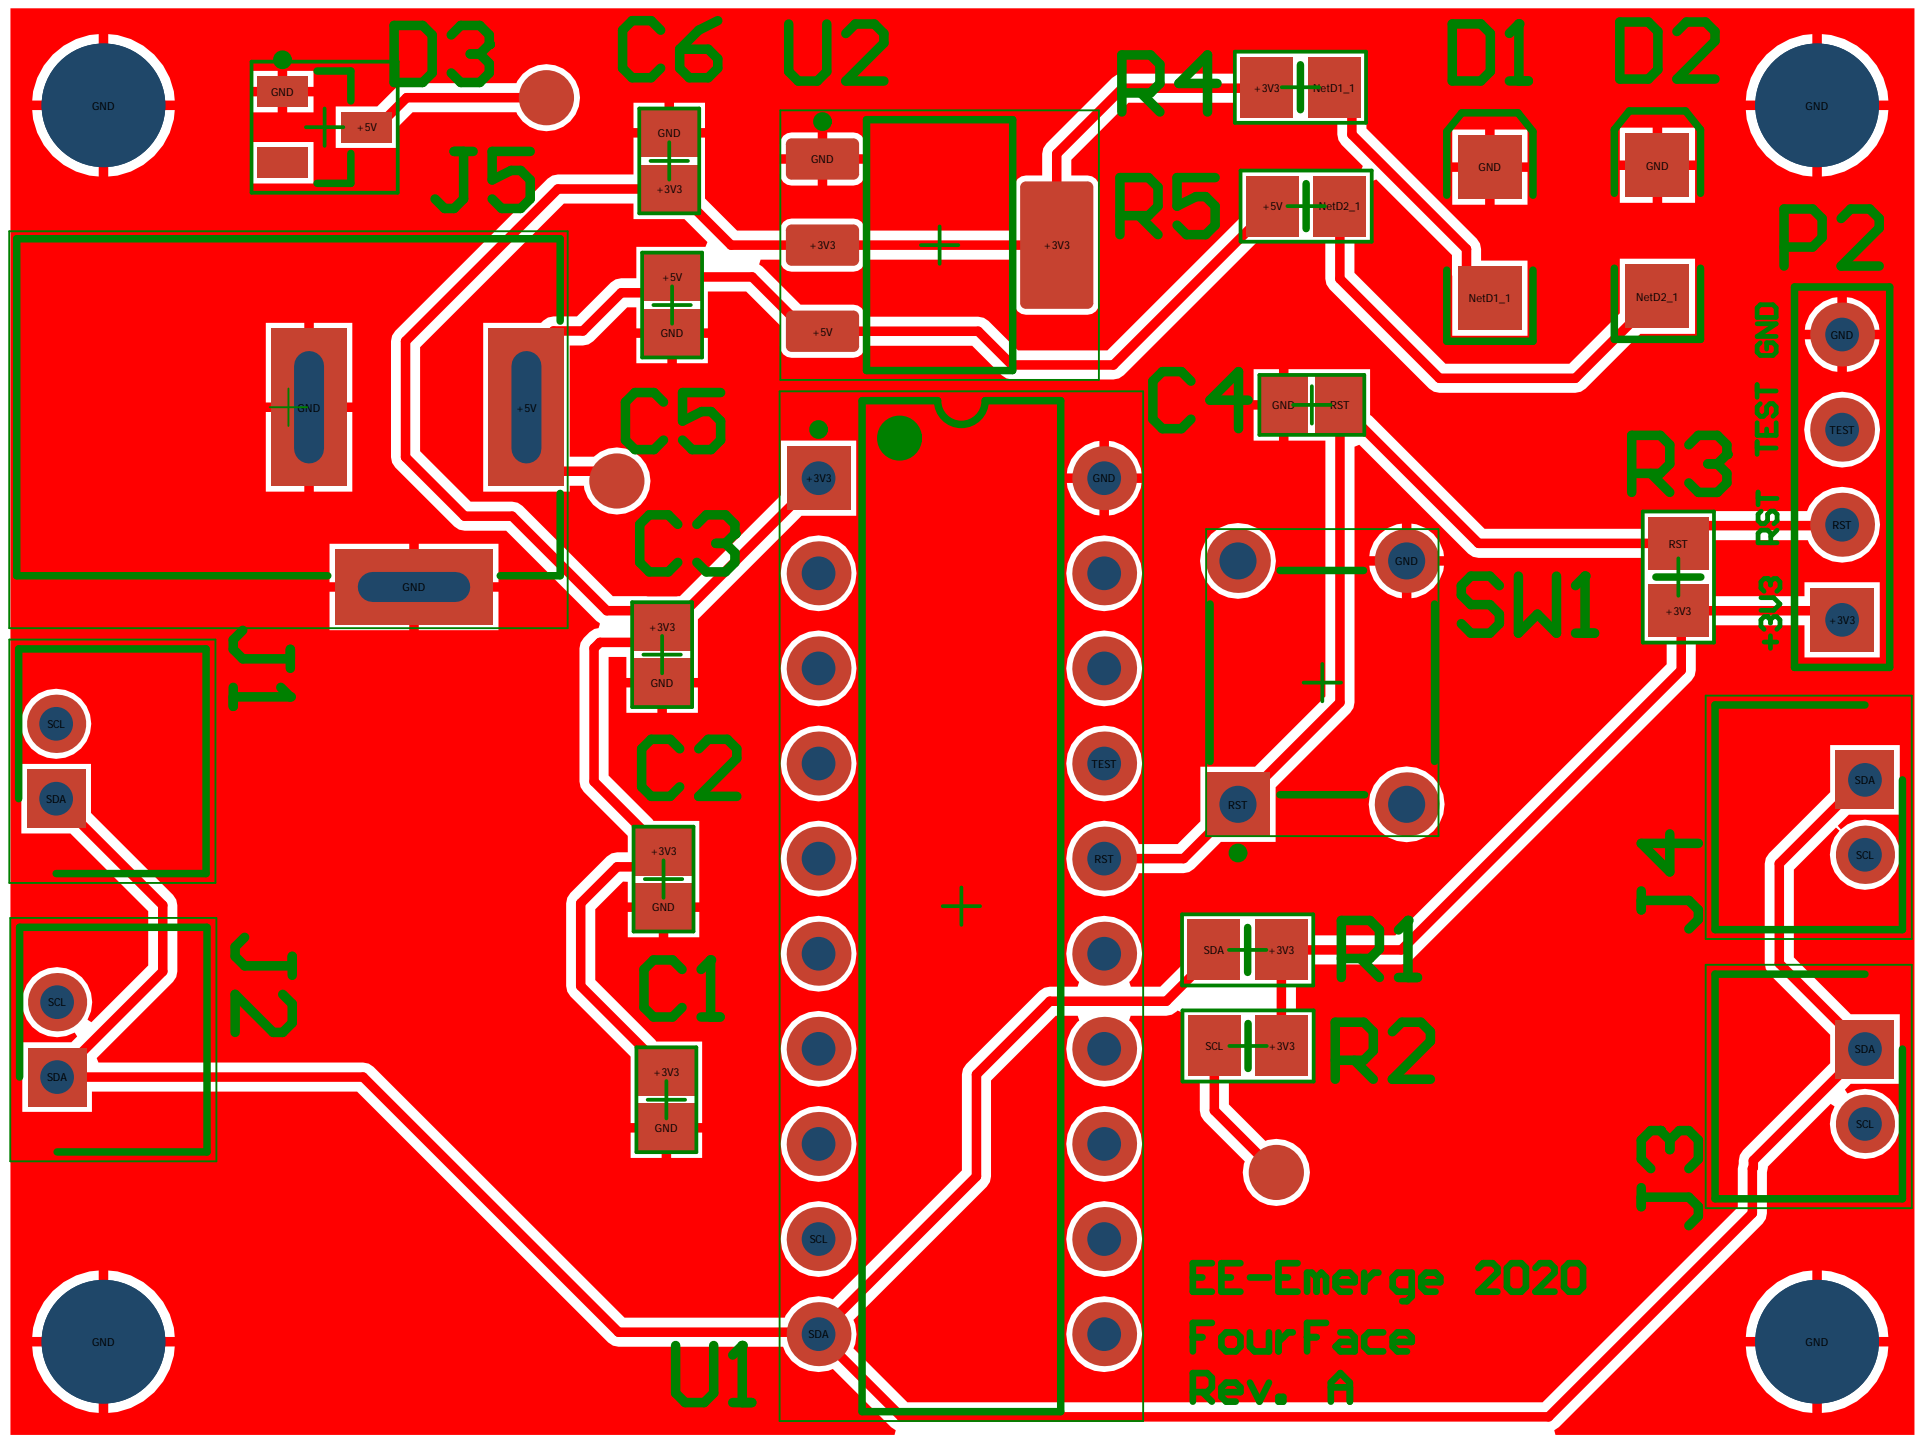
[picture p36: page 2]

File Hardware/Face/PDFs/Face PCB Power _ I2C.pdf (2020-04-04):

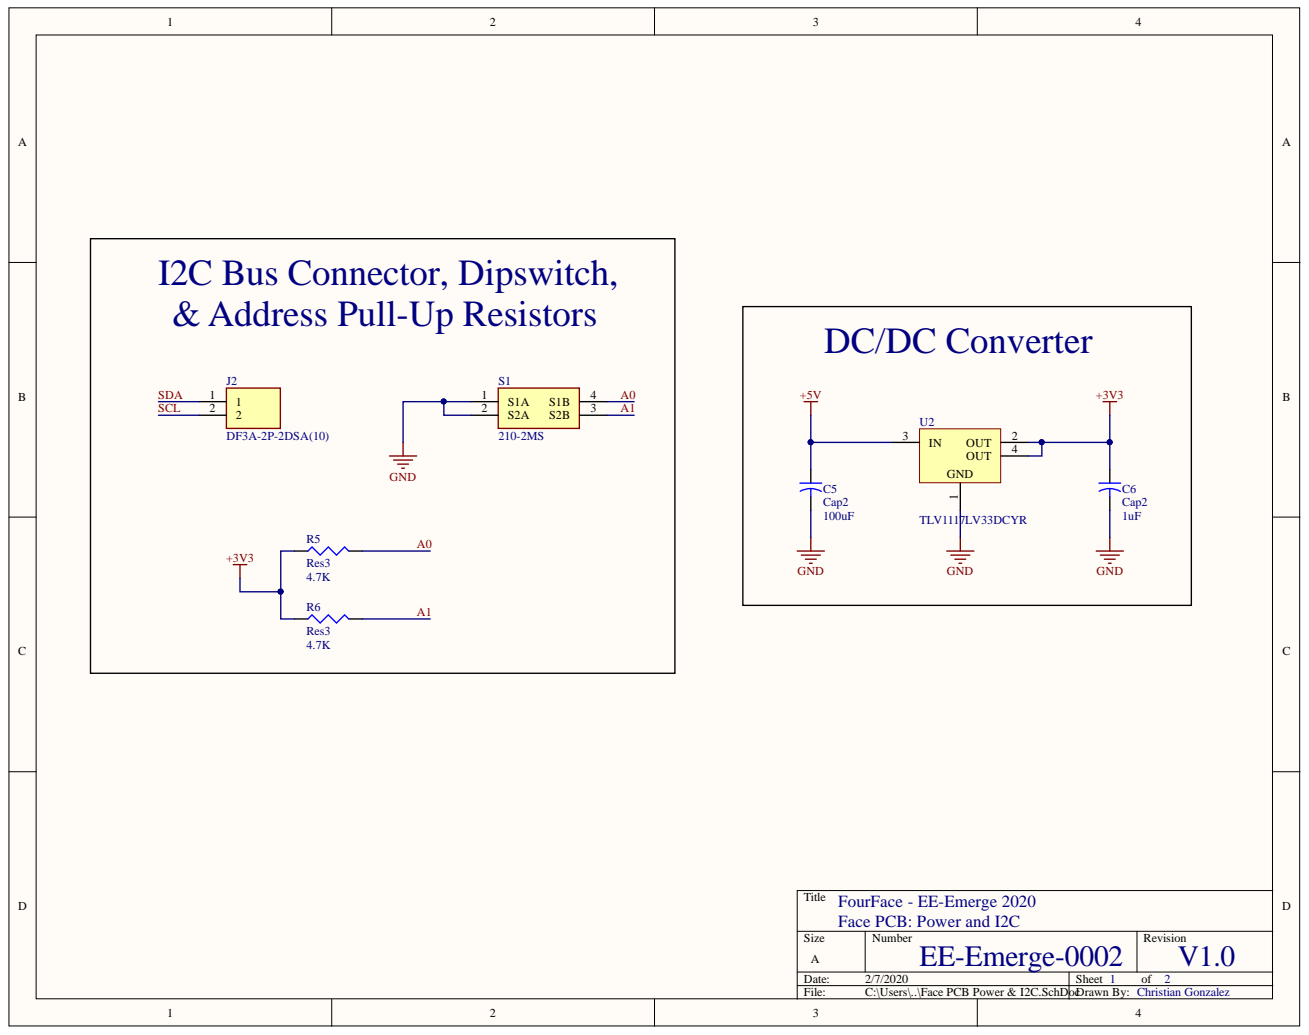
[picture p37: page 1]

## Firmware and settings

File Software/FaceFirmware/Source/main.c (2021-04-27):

#include <msp430.h>
#include "ws2812.h"

#include <msp430g2553.h>
#include <stdint.h>
#include "structure.h"
#include "CTS_Layer.h"

#include "UART/uart.h"

//Functions
//LEDs
void setColorsShowStrip(uint8_t square, uint8_t color);
void receivePattern(void);
void sendPattern(void);
void resetLITSquares(void);
//Cap Touch Sensors
int runCapTouch();
void InitCapSenseButtons(void);
//Communications
void establishContact(void);
void UART_TX(char * tx_data);
void flashColor(ColorMap color);

//CHECK_BIT(temp, n - 1) where n is bits from right
#define CHECK_BIT(NUM,POS) ((NUM) & (0x1<<(POS)))

#define LEDS_PER_SQUARE (NUM_LEDS/9)
#define DELAY_100ms (800000)
unsigned i = 0;


//Enums
typedef enum  ledStripPins
{
    SQUARES_A,
    SQUARES_B,
    SQUARES_C,
    SQUARES_D,
    SQUARES_E,
    SQUARES_F,
    SQUARES_G,
    SQUARES_H,
    SQUARES_I,
    NUM_SQUARES
} squareNames;

////////////////////////////////////////
//SQUARE NUMBER LAYOUT BASED ON WIRING
////////////////////////////////////////
//  G | F | E  |  6 | 5 | 4  |  1.5 | 1.4 | 1.0
//  ---------  |  ---------  |  ---------------
//  H | C | D  |  7 | 2 | 3  |  2.2 | 2.1 | 1.6
//  ---------  |  ---------  |  ---------------
//  I | B | A  |  8 | 1 | 0  |  2.6 | 2.7 | 2.4

//2.4, 2.7, 2.1, 1.6, 1.0, 1.4, 1.5, 2.2, 2.6

uint8_t state = 0;
uint8_t litSquares[9] = {0};
int main(void)
{
    WDTCTL = WDTPW + WDTHOLD;  // Stop WDT
    if (CALBC1_16MHZ==0xFF)    // If calibration constant erased
    {
        while(1);              // do not load, trap CPU!!
    }
    DCOCTL = 0; // Select lowest DCOx and MODx
    // configure clock to 16 MHz
    BCSCTL1 = CALBC1_16MHZ;    // DCO = 16 MHz
    DCOCTL = CALDCO_16MHZ;
    
    /* Configure P1.1 and P1.2 for UART (USCI_A0) */
    P1SEL |= BIT1 + BIT2;                     // P1.1 = RXD, P1.2=TXD
    P1SEL2 |= BIT1 + BIT2;

    /* Global interrupt enable */
    __enable_interrupt();
    __bis_SR_register(GIE);

    uart_init();
    InitCapSenseButtons();
    initStrip();
    establishContact();
    setColorsShowStrip(SQUARES_C, COLOR_BLUE);

    //Ready up
    while(runCapTouch() != SQUARES_C) {
        __delay_cycles(300);
    }
    flashColor(COLOR_BLUE);
    uart_putchar('R');

    int UARTStreamChar;
    while (1)
    {
        UARTStreamChar = uart_getchar();
        if (UARTStreamChar != -1) {
            if (UARTStreamChar == 'R') {
                continue;
            }
            else if (UARTStreamChar == 'N') {
                receivePattern();
                sendPattern();
            }
            else if (UARTStreamChar == 'W') {
                fillStrip(COLOR_GREEN);
                showStrip();
                while(1){};
            }
            else if (UARTStreamChar == 'L') {
                fillStrip(COLOR_RED);
                showStrip();
                while(1){};
            }
        }
    }
}


void setColorsShowStrip(uint8_t square, uint8_t colorNum)
{
    ColorMap color;
    switch(colorNum)
    {
    case 0:
        color = COLOR_OFF;
        break;
    case 1:
        color = COLOR_RED;
        break;
    case 2:
        color = COLOR_GREEN;
        break;
    case 3:
        color = COLOR_BLUE;
    }

    ColorMap currentColor = COLOR_OFF;
    //Toggle passed square
    litSquares[square] = !litSquares[square];
    int k = 0;
    for (i = NUM_SQUARES; i > 0; i--) {
        currentColor = COLOR_OFF;
        if (litSquares[i])
            currentColor = color;
        for (k = i * LEDS_PER_SQUARE; k < (i + 1) * LEDS_PER_SQUARE; k++) 
            setLEDColor(k, currentColor);
    }
    showStrip();
}


void receivePattern(void)
{
    resetLITSquares();

    int square = -1;
    int color = -1;
    int state = 0;
    int UARTStreamChar = uart_getchar();
    do
    {
        if(UARTStreamChar != -1)
        {
            if(state == 0)
            {
                square = UARTStreamChar  - '0';
                state = 1;
            }
            else if(state == 1)
            {
                color = UARTStreamChar  - '0';
                state = 0;
                setColorsShowStrip(square, color);
                for (i = 1; i > 0; i--) {
                    __delay_cycles(10 * DELAY_100ms);
                }
                uart_putchar('D');
            }
        }
        UARTStreamChar = uart_getchar();
    } while (UARTStreamChar != 'E');
    flashColor(COLOR_BLUE);
    uart_putchar('D');
}


void sendPattern(void) {
    resetLITSquares();

    int capTouchValue = -1;
    int UARTStreamChar = -1;
    uint8_t playerLoses = 0;
    uint8_t square = 0;
    uint8_t color = 0;
    while(1) {
        capTouchValue = runCapTouch();
        if (capTouchValue != 0) {
            uart_putchar('P');
            uart_putchar(capTouchValue);

            while(1)
            {
                UARTStreamChar = uart_getchar();
                if(UARTStreamChar != -1)
                {
                    if (state == 0)
                    {
                        square = UARTStreamChar  - '0';
                        state = 1;
                    }
                    else if (state == 1)
                    {
                        color = UARTStreamChar  - '0';
                        state = 0;
                        setColorsShowStrip(square, color);
                        if (color == COLOR_RED) {
                            playerLoses = 1;
                        }
                        break;
                    }
                }
            }
        }
        if (uart_getchar() == 'E')
            break;
    }
    if (!playerLoses) {
        flashColor(COLOR_GREEN);
    }
    uart_putchar('D');
}


void resetLITSquares(void)
{
    for (i = 9; i > 0; i--) {
        litSquares[i] = 0;
    }
}


int runCapTouch()
{
    int result = 0;
    if (TI_CAPT_Button(&buttonSensor0))
        result = SQUARES_A;
    else if (TI_CAPT_Button(&buttonSensor1))
        result = SQUARES_B;
    else if (TI_CAPT_Button(&buttonSensor2))
        result = SQUARES_C;
    else if (TI_CAPT_Button(&buttonSensor3))
        result = SQUARES_D;
    else if (TI_CAPT_Button(&buttonSensor4))
        result = SQUARES_E;
    else if (TI_CAPT_Button(&buttonSensor5))
        result = SQUARES_F;
    else if (TI_CAPT_Button(&buttonSensor6))
        result = SQUARES_G;
    else if (TI_CAPT_Button(&buttonSensor7))
        result = SQUARES_H;
    else if (TI_CAPT_Button(&buttonSensor8))
        result = SQUARES_I;
    return result;
}


void InitCapSenseButtons(void)
{
    // Init each of the cap sense sensor. 
    TI_CAPT_Init_Baseline(&buttonSensor0);       // Establish baseline
    TI_CAPT_Update_Baseline(&buttonSensor0, 10); // Average 10 baseline measurements
    TI_CAPT_Init_Baseline(&buttonSensor1);
    TI_CAPT_Update_Baseline(&buttonSensor1, 10);
    TI_CAPT_Init_Baseline(&buttonSensor2);
    TI_CAPT_Update_Baseline(&buttonSensor2, 10);
    TI_CAPT_Init_Baseline(&buttonSensor3);
    TI_CAPT_Update_Baseline(&buttonSensor3, 10);
    TI_CAPT_Init_Baseline(&buttonSensor4);
    TI_CAPT_Update_Baseline(&buttonSensor4, 10);
    TI_CAPT_Init_Baseline(&buttonSensor5);
    TI_CAPT_Update_Baseline(&buttonSensor5, 10);
    TI_CAPT_Init_Baseline(&buttonSensor6);
    TI_CAPT_Update_Baseline(&buttonSensor6, 10);
    TI_CAPT_Init_Baseline(&buttonSensor7);
    TI_CAPT_Update_Baseline(&buttonSensor7, 10);
    TI_CAPT_Init_Baseline(&buttonSensor8);
    TI_CAPT_Update_Baseline(&buttonSensor8, 10);
    TI_CAPT_Update_Tracking_Rate(TRIDOI_VSLOW | TRADOI_FAST);   // Set baseline update rate to VSLOW in direction of interest
}


void establishContact(void)
{
    int byteReceived = 0;
    while (!byteReceived) {
        if (uart_getchar() == 'R') {
            byteReceived = 1;
            uart_putchar('R');
        }
    }
//    uart_clearStream();
}

void flashColor(ColorMap color)
{
//    clearStrip();
//    showStrip();

    for (i = 1; i > 0; i--) {
        __delay_cycles(5 * DELAY_100ms);
    }

    fillStrip(color);
    showStrip();

    for (i = 1; i > 0; i--) {
        __delay_cycles(10 * DELAY_100ms);
    }

    clearStrip();
    showStrip();
}

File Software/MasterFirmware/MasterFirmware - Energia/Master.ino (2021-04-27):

//Includes for game
#include <stdbool.h>
#include <stdio.h> 
#include <stdlib.h> 

//////////////MASTER.C GAME CODE//////////////////////////////
typedef struct 
{
    int score;
    bool eliminated;
} Player;

typedef struct 
{
    int totalRoundCount;
    int crntRound;
    int initialSquareCount; // How many squares emitted in the pattern
    //Difficulty
} Game;


//Enums
typedef enum  ledStripPins
{
    SQUARES_A,
    SQUARES_B,
    SQUARES_C,
    SQUARES_D,
    SQUARES_E,
    SQUARES_F,
    SQUARES_G,
    SQUARES_H,
    SQUARES_I,
    NUM_SQUARES
} squareNames;

typedef enum  colors
{
    COLOR_OFF,
    COLOR_RED,
    COLOR_GREEN,
    COLOR_BLUE,
    NUM_COLOR
} LEDColors;

//Functions
//Communications
void establishContact();
void delayUntil(char c);
//Game
void startGame(int totalRoundCount, int initialSquareCount); //Round time in ms
void initializePlayer(Player *player);
int* generatePattern(const int sequenceLength); //Returns new pattern. Should only be called from newRound();
int* newRound(const int sequenceLength); 
void displayPattern(int* roundPattern, int sequenceLength);
void receiveComparePattern(int* roundPattern, int sequenceLength);


//Globals
static Game game;
static Player* player1 = NULL;
static Player* player2 = NULL;
static Player* player3 = NULL;
static Player* player4 = NULL;


// initialize game and players
uint16_t buttonStates = 0x0;
int sizePatternArray;
int* pattern;
uint16_t pressedPlate = 0;


// the setup routine runs once when you press reset:
void setup() {                
    Serial1.begin(9600); 
    randomSeed(analogRead(A15));
    establishContact(); // send a byte to establish contact until receiver responds 
    
    startGame(3, 1);
    player1 = (Player*)malloc(sizeof(Player));
    player2 = (Player*)malloc(sizeof(Player));
    player3 = (Player*)malloc(sizeof(Player));
    player4 = (Player*)malloc(sizeof(Player));
    initializePlayer(player1);
    initializePlayer(player2);
    initializePlayer(player3);
    initializePlayer(player4);
}

//////////////////////////////
//MAIN FUNCTION
//////////////////////////////
unsigned i = 0;
void loop() {
    delayUntil('R');

    int sequenceLength = 0;
    int* pattern;
    for (i = game.totalRoundCount; i > 0 && !player1->eliminated; i--) {
        Serial1.print('N');
//        if ((*pattern) != 0) {
//            free(pattern);
//        }
        sequenceLength = game.initialSquareCount + game.crntRound;
        pattern = newRound(sequenceLength);
        receiveComparePattern(pattern, sequenceLength);
    }

    if (!player1->eliminated) {
        Serial1.print('W');
        while(1) {};
    }
    else {
        Serial1.print('L');
        while(1) {};
    }
}


//Ensures connection to slave is good
void establishContact() {
  while (Serial1.read() != 'R') {
    Serial1.print('R');
    delay(300);
  }
}


//Loop until a char is received from UART stream
void delayUntil(char c) {
    while (Serial1.read() != c) {
        delay(300);
    }
}


//Initialize game values
void startGame(int totalRoundCount, int initialSquareCount)
{
    game.totalRoundCount = totalRoundCount;
    game.initialSquareCount = initialSquareCount;
    game.crntRound = 0;
}


//Initialize player values for beginning of game
void initializePlayer(Player *player)
{
    player->score = 0;
    player->eliminated = false;
}


//Generate a new random pattern for the new round
int* generatePattern(const int sequenceLength)
{
    int* newPattern;
    //Allocate a block of memory the length of sequenceLength with each block large enough for an int
    newPattern = (int*)calloc(sequenceLength, sizeof(int));
    int i;
    for (i = 0; i < sequenceLength; i++) {
//        *(newPattern + i) = (rand() % (SQUARES_I - SQUARES_A + 1)) + SQUARES_A;
            *(newPattern + i) = random(SQUARES_A, SQUARES_I + 1);
    }
    return newPattern;
}


int* newRound(const int sequenceLength)
{
    int* pattern = generatePattern(sequenceLength);
    game.crntRound++;
    displayPattern(pattern, sequenceLength);
    return pattern;
}
 
 
void displayPattern(int* roundPattern, int sequenceLength)
{
    uint8_t square = 0;
    int i = 0;
    for (; i < sequenceLength; i++)
    {
        square = roundPattern[i];
        Serial1.print(square);
        Serial1.print(COLOR_BLUE);
        delayUntil('D');
    }
    Serial1.print('E');
    delayUntil('D');
}

void receiveComparePattern(int* roundPattern, int sequenceLength) {
    int pressedSquare;
    int i = 0;
    for (; i < sequenceLength && !player1->eliminated; i++) {
        delayUntil('P');
        pressedSquare = Serial1.read();
        if (pressedSquare == roundPattern[i]) {
            Serial1.print(pressedSquare);
            Serial1.print(COLOR_GREEN);
            player1->score++;
        }
        else {
            Serial1.print(pressedSquare);
            Serial1.print(COLOR_RED);
            player1->eliminated = true;
        }
    }
    Serial1.print('E');
    delayUntil('D');
}

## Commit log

2020-04-04 Added photos of Schematic
2020-04-04 Added files again
    [Central PCB Enclosure Lid.step, Central PCB Enclosure.step, Central PCB.PcbDoc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]
2020-04-05 Added Gerber Files as zip
2020-04-15 Uploaded Face and Master Firmware Files
    These are the files that were last updated at the end of Winter Quarter 2020. As of the Spring quarter, no changes have been made yet.
2020-04-17 Added Christian's updated model an connectors
    [Assembly v6.step, Corner Cube Fastener v5.step, Dowel v2.step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]
2020-04-18 Uploaded OneSquarePrototype .step and .png
    [OneSquarePrototype v6.step]
2020-04-25 Create Central PCB
2020-04-28 Deleted Anthony's Flowchart
    I created a new, more detailed flowchart that encapsulates the master and slave firmware better.
2020-04-28 New Flowchart
    Added the new flowchart pdf for the master and slave firmware. The flowcharts are both contained in the same pdf file.
2020-05-06 restructured hardware files to be on a per project basis
    [Central PCB.PcbDoc, Central PCB.PrjPcb, Central PCB.SchDoc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]
2020-05-09 New Face Firmware
    New:
    Can now receive and send data over UART
    Correctly toggles specific square with specific color
    Bugs:
    Capacistive Touch Not Working - Issue with initalization
    [main.c, ws2812.c]
2020-05-10 Fixed bug with selecting square on slave
    [Master.ino, main.c]
2020-05-23 Capacitive Touch Sensors Implimented
    Changes:
    New Compiler: Switched from "GCC" to "TI 20.2.1.LTS"
    Changed cap sence pin 1.1 to 2.6 because 1.1 is used for UART
    Deleted "msp430g2553.id" b/c not needed
    [CTS_HAL.obj, CTS_Layer.obj, main.obj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]
2020-05-26 UART Communication Rework
    Slave Changes:
    UART rework using "http://www.simplyembedded.org/" msp430 launchpad
    Receives and displays pattern from Master correctly
    Sends cap touch values to master correctly
    Master Changes:
    Can correctly send square and color to slave
    Receives cap touch values from slave
    Correctly moves on to next pattern once previous one completed
    TODOs:
    Player cannot lose
    Make entire face flash red when player loses
    Stop game when player loses
    Rework and improve communication code
    [main.obj, structure.obj]
2020-05-26 Improved readability and effeciency
    Slave:
    Changed layout of code to resemble state diagram.
    After all is initiated, it runs through a while loop checking for
    incoming chars. There are 4 possible characters it can receieve in this
    base state to move it into a new state.
    'R': Left in stream from connection setup. Ignore this
    'N': New pattern to display then have player reenter.
    'W': Player wins.
    'L': Player loses.
    Sometimes not all squares in pattern or displays properly or some are
    skipped.
    Master:
    Changed code to follow new slave layout.
    Iterates through for loop where each iteration is a new round in the
    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
    [CTS_HAL.obj, CTS_Layer.obj, main.obj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]
